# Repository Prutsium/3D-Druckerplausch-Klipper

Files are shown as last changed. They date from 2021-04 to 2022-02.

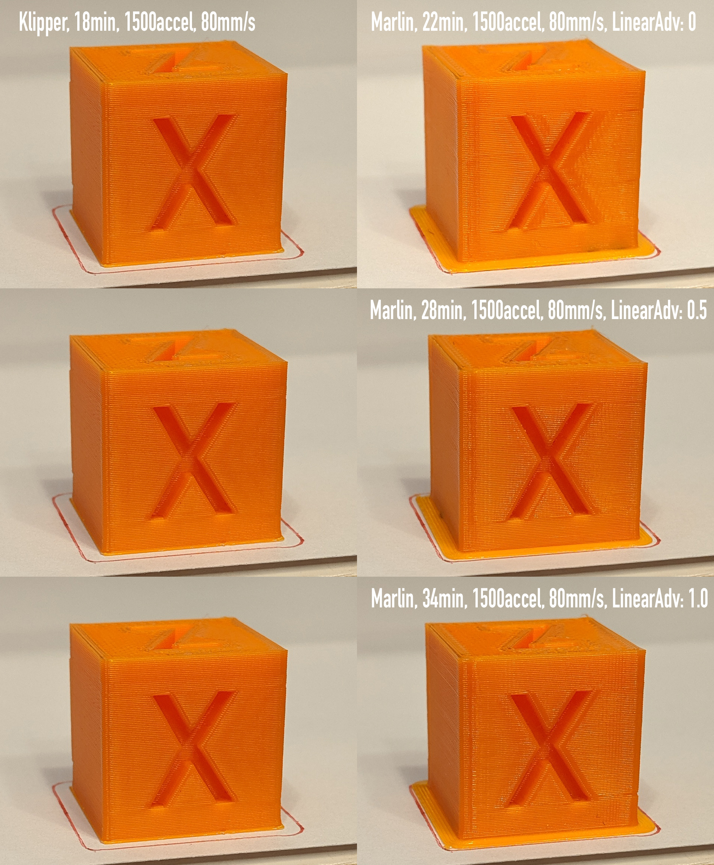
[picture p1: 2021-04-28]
images/KlipperVsMarlin.jpg

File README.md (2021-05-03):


Find us on Telegram: https://t.me/Druckerplausch

Repo for config file(s) for Prusa MK3(S)(+) and others with Klipper

Please see the wiki for advanced information how we set up Klipper on our Prusa printers.

This repository is meant in general for klipper but has a big focus on Prusa MK3(S)(+) with Klipper.
We try to collect here first of all working and complete configurations and these have been build up in a modular way so it would be easy to add or remove something or when we add a specific config for a specific part you wont need to modify your configuration but just include it in your original configuration.

We are still in a setup process but we try to document as much as possible.

The Wiki will be a main guideline on how to flash but also explanations how certain parts work.

# ToDo

- Klipper Setup on Raspberry and Prusa
- Restore Prusa firmware
- Config file description and how includes work
- 3-Axis tilt module -> resonance etc
- ...

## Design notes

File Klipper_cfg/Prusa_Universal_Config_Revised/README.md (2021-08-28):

This is my new approach of making configs since i had to take care of 5 different configs i went for a Universal Prusa / Bear config set.
The most of you are using the Prusa / Bear with the stock Einsy. Personally i dont use the Einsy anymore but i use a Duet 3 Mini 5+ and a Octopus board.
This made keeping the other configs up to date for me difficult and as said had to replicate my edits on 5 other configs.

For this reason i went for a more universal config where more things are splitted out and makes updates more easy.
The main file will be printer.cfg but you will need all files to copu to your klipper_config.

If you like to add something dont edit the files as when i make updates those will be overwritten.
Instead of that add them to the printer.cfg at the end as they will overrule what is in the configs.
You even dont need to remove the old part as the new part will overwrite those settings.

The selection is by default for a stock prusa with the stock extruder and a Einsy board.
If you want to use something else then remove the corrospondig # infront of that config.

Contribution is appriciated please use the issue tracker from Git and if interesting / helpfull we can add those requests.

This config is made of parts of my own but also scraped from various Klipper channels.
A special thanks to Khuaong for helping with the MMU part, Q66 for some great additions and Alexz who is always assisting if i want to create some stupid macro :)

Make sure you make a copy of your old klipper configuration before copying this to the klipper_config folder.
Due i have to use some defaults for PID and Z_Offset i suggest you copy from your old config the part that say's do not edit like the following example
#*# <---------------------- SAVE_CONFIG ---------------------->
#*# DO NOT EDIT THIS BLOCK OR BELOW. The contents are auto-generated.

Copy the whole block with contents and put this in the printer.cfg and run PID tuning after that for the bed and extruder.

Also add your MCU in mcu.cfg as then i can create update on the cfg's without overwriteing your MCU settings
I use a simplified way of MCU selection through Symlinks so you dont have to bother about the wier name like: usb-Klipper_stm32f446xx_3D002A000950534E4E313020-if00
But after creating a Symlink it would be: btt-octopus-11.

To create a Symlink use the following commands on your Pi:
pi@fluiddpi:~ $ lsusb
Bus 002 Device 001: ID 1d6b:0003 Linux Foundation 3.0 root hub
Bus 001 Device 037: ID 1d50:614e OpenMoko, Inc.
Bus 001 Device 002: ID 2109:3431 VIA Labs, Inc. Hub
Bus 001 Device 001: ID 1d6b:0002 Linux Foundation 2.0 root hub
pi@fluiddpi:~ $

In my case i am interested in the ID of the OpenMoko device what is the Octopus.
Next is to create the Symlink with the following command: (this will open the Nano editor with a blanc file)
sudo nano /etc/udev/rules.d/99-usb-serial.rules
Edit this file and put there: (in my example you see it for the Octopus)
SUBSYSTEMS=="usb", ATTRS{idProduct}=="614e",  ATTRS{idVendor}=="1d50", ACTION=="add", SYMLINK+="btt-octopus-11"

Save this file with CTRL-X and check if the printer has now a new name with ls /dev it should show there the name of the printer.
Now edit mcu.cfg (n ano ~/klipper_config/mcu.cfg ) and make the serial line like this (with your printer name)
serial: /dev/btt-octopus-11
Save it with CTRL-X and done you now can reach the printer by an easy name.

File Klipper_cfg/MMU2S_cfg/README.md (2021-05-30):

This is a new approach to use the MMU as the basis from Kakou was to restricted

User settings to do:
variable_bowden_load_length1: 505
variable_bowden_load_length2: 5
variable_bowden_unload_length: 520
variable_load_in_extruder: 52 # how much filament to load into extruder
variable_unload_in_extruder1: 32 
variable_unload_in_extruder2: 50

Dont forget to update your start Gcode in SuperSlicer and make sure it exports Klipper Gcode.
SET_GCODE_VARIABLE MACRO=START_PRINT_MMU VARIABLE=BED_TEMP VALUE=[first_layer_bed_temperature]
SET_GCODE_VARIABLE MACRO=START_PRINT_MMU VARIABLE=EXTRUDER_TEMP VALUE=[first_layer_temperature]
SET_GCODE_VARIABLE MACRO=START_PRINT_MMU VARIABLE=LOAD VALUE=[initial_tool]
START_PRINT_MMU

And as end print Gcode: END_PRINT_MMU

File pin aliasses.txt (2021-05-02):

# This file contains common board aliases for Arduino (and similar)
# boards.

# See docs/Config_Reference.md for a description of parameters.

# Arduino aliases for atmega168/328/328p boards
[board_pins arduino-standard]
aliases:
    ar0=PD0, ar1=PD1, ar2=PD2, ar3=PD3, ar4=PD4,
    ar5=PD5, ar6=PD6, ar7=PD7, ar8=PB0, ar9=PB1,
    ar10=PB2, ar11=PB3, ar12=PB4, ar13=PB5, ar14=PC0,
    ar15=PC1, ar16=PC2, ar17=PC3, ar18=PC4, ar19=PC5,
    analog0=PC0, analog1=PC1, analog2=PC2, analog3=PC3, analog4=PC4,
    analog5=PC5, analog6=PE0, analog7=PE1

# Arduino aliases for atmega2560/1280 (Arduino mega) boards
[board_pins arduino-mega]
aliases:
    ar0=PE0, ar1=PE1, ar2=PE4, ar3=PE5, ar4=PG5,
    ar5=PE3, ar6=PH3, ar7=PH4, ar8=PH5, ar9=PH6,
    ar10=PB4, ar11=PB5, ar12=PB6, ar13=PB7, ar14=PJ1,
    ar15=PJ0, ar16=PH1, ar17=PH0, ar18=PD3, ar19=PD2,
    ar20=PD1, ar21=PD0, ar22=PA0, ar23=PA1, ar24=PA2,
    ar25=PA3, ar26=PA4, ar27=PA5, ar28=PA6, ar29=PA7,
    ar30=PC7, ar31=PC6, ar32=PC5, ar33=PC4, ar34=PC3,
    ar35=PC2, ar36=PC1, ar37=PC0, ar38=PD7, ar39=PG2,
    ar40=PG1, ar41=PG0, ar42=PL7, ar43=PL6, ar44=PL5,
    ar45=PL4, ar46=PL3, ar47=PL2, ar48=PL1, ar49=PL0,
    ar50=PB3, ar51=PB2, ar52=PB1, ar53=PB0, ar54=PF0,
    ar55=PF1, ar56=PF2, ar57=PF3, ar58=PF4, ar59=PF5,
    ar60=PF6, ar61=PF7, ar62=PK0, ar63=PK1, ar64=PK2,
    ar65=PK3, ar66=PK4, ar67=PK5, ar68=PK6, ar69=PK7,
    analog0=PF0, analog1=PF1, analog2=PF2, analog3=PF3, analog4=PF4,
    analog5=PF5, analog6=PF6, analog7=PF7, analog8=PK0, analog9=PK1,
    analog10=PK2, analog11=PK3, analog12=PK4, analog13=PK5, analog14=PK6,
    analog15=PK7,
    # Marlin adds these additional aliases
    ml70=PG4, ml71=PG3, ml72=PJ2, ml73=PJ3, ml74=PJ7,
    ml75=PJ4, ml76=PJ5, ml77=PJ6, ml78=PE2, ml79=PE6,
    ml80=PE7, ml81=PD4, ml82=PD5, ml83=PD6, ml84=PH2,
    ml85=PH7

# Aliases for atmega644p (Sanguino boards)
[board_pins sanguino]
aliases:
    ar0=PB0, ar1=PB1, ar2=PB2, ar3=PB3, ar4=PB4,
    ar5=PB5, ar6=PB6, ar7=PB7, ar8=PD0, ar9=PD1,
    ar10=PD2, ar11=PD3, ar12=PD4, ar13=PD5, ar14=PD6,
    ar15=PD7, ar16=PC0, ar17=PC1, ar18=PC2, ar19=PC3,
    ar20=PC4, ar21=PC5, ar22=PC6, ar23=PC7, ar24=PA0,
    ar25=PA1, ar26=PA2, ar27=PA3, ar28=PA4, ar29=PA5,
    ar30=PA6, ar31=PA7,
    analog0=PA0, analog1=PA1, analog2=PA2, analog3=PA3, analog4=PA4,
    analog5=PA5, analog6=PA6, analog7=PA7

# Aliases for atsam3x8e (Arduino Due boards)
[board_pins arduino-due]
aliases:
    ar0=PA8, ar1=PA9, ar2=PB25, ar3=PC28, ar4=PA29,
    ar5=PC25, ar6=PC24, ar7=PC23, ar8=PC22, ar9=PC21,
    ar10=PA28, ar11=PD7, ar12=PD8, ar13=PB27, ar14=PD4,
    ar15=PD5, ar16=PA13, ar17=PA12, ar18=PA11, ar19=PA10,
    ar20=PB12, ar21=PB13, ar22=PB26, ar23=PA14, ar24=PA15,
    ar25=PD0, ar26=PD1, ar27=PD2, ar28=PD3, ar29=PD6,
    ar30=PD9, ar31=PA7, ar32=PD10, ar33=PC1, ar34=PC2,
    ar35=PC3, ar36=PC4, ar37=PC5, ar38=PC6, ar39=PC7,
    ar40=PC8, ar41=PC9, ar42=PA19, ar43=PA20, ar44=PC19,
    ar45=PC18, ar46=PC17, ar47=PC16, ar48=PC15, ar49=PC14,
    ar50=PC13, ar51=PC12, ar52=PB21, ar53=PB14, ar54=PA16,
    ar55=PA24, ar56=PA23, ar57=PA22, ar58=PA6, ar59=PA4,
    ar60=PA3, ar61=PA2, ar62=PB17, ar63=PB18, ar64=PB19,
    ar65=PB20, ar66=PB15, ar67=PB16, ar68=PA1, ar69=PA0,
    ar70=PA17, ar71=PA18, ar72=PC30, ar73=PA21, ar74=PA25,
    ar75=PA26, ar76=PA27, ar77=PA28, ar78=PB23,
    analog0=PA16, analog1=PA24, analog2=PA23, analog3=PA22, analog4=PA6,
    analog5=PA4, analog6=PA3, analog7=PA2, analog8=PB17, analog9=PB18,
    analog10=PB19, analog11=PB20

# Aliases for Adafruit GrandCentral boards (samd51)
[board_pins adafruit-grandcentral]
aliases:
    ar0=PB25, ar1=PB24, ar2=PC18, ar3=PC19, ar4=PC20,
    ar5=PC21, ar6=PD20, ar7=PD21, ar8=PB18, ar9=PB2,
    ar10=PB22, ar11=PB23, ar12=PB0, ar13=PB1, ar14=PB16,
    ar15=PB17, ar16=PC22, ar17=PC23, ar18=PB12, ar19=PB13,
    ar20=PB20, ar21=PB21, ar22=PD12, ar23=PA15, ar24=PC17,
    ar25=PC16, ar26=PA12, ar27=PA13, ar28=PA14, ar29=PB19,
    ar30=PA23, ar31=PA22, ar32=PA21, ar33=PA20, ar34=PA19,
    ar35=PA18, ar36=PA17, ar37=PA16, ar38=PB15, ar39=PB14,
    ar40=PC13, ar41=PC12, ar42=PC15, ar43=PC14, ar44=PC11,
    ar45=PC10, ar46=PC6, ar47=PC7, ar48=PC4, ar49=PC5,
    ar50=PD11, ar51=PD8, ar52=PD9, ar53=PD10, ar54=PA2,
    ar55=PA5, ar56=PB3, ar57=PC0, ar58=PC1, ar59=PC2,
    ar60=PC3, ar61=PB4, ar62=PB5, ar63=PB6, ar64=PB7,
    ar65=PB8, ar66=PB9, ar67=PA4, ar68=PA6, ar69=PA7,
    analog0=PA2, analog1=PA5, analog2=PB3, analog3=PC0, analog4=PC1,
    analog5=PC2, analog6=PC3, analog7=PB4, analog8=PB5, analog9=PB6,
    analog10=PB7, analog11=PB8, analog12=PB9, analog13=PA4, analog14=PA6,
    analog15=PA7

# Aliases for Beaglebone boards
[board_pins beaglebone]
aliases:
    P8_3=gpio1_6, P8_4=gpio1_7, P8_5=gpio1_2,
    P8_6=gpio1_3, P8_7=gpio2_2, P8_8=gpio2_3,
    P8_9=gpio2_5, P8_10=gpio2_4, P8_11=gpio1_13,
    P8_12=gpio1_12, P8_13=gpio0_23, P8_14=gpio0_26,
    P8_15=gpio1_15, P8_16=gpio1_14, P8_17=gpio0_27,
    P8_18=gpio2_1, P8_19=gpio0_22, P8_20=gpio1_31,
    P8_21=gpio1_30, P8_22=gpio1_5, P8_23=gpio1_4,
    P8_24=gpio1_1, P8_25=gpio1_0, P8_26=gpio1_29,
    P8_27=gpio2_22, P8_28=gpio2_24, P8_29=gpio2_23,
    P8_30=gpio2_25, P8_31=gpio0_10, P8_32=gpio0_11,
    P8_33=gpio0_9, P8_34=gpio2_17, P8_35=gpio0_8,
    P8_36=gpio2_16, P8_37=gpio2_14, P8_38=gpio2_15,
    P8_39=gpio2_12, P8_40=gpio2_13, P8_41=gpio2_10,
    P8_42=gpio2_11, P8_43=gpio2_8, P8_44=gpio2_9,
    P8_45=gpio2_6, P8_46=gpio2_7, P9_11=gpio0_30,
    P9_12=gpio1_28, P9_13=gpio0_31, P9_14=gpio1_18,
    P9_15=gpio1_16, P9_16=gpio1_19, P9_17=gpio0_5,
    P9_18=gpio0_4, P9_19=gpio0_13, P9_20=gpio0_12,
    P9_21=gpio0_3, P9_22=gpio0_2, P9_23=gpio1_17,
    P9_24=gpio0_15, P9_25=gpio3_21, P9_26=gpio0_14,
    P9_27=gpio3_19, P9_28=gpio3_17, P9_29=gpio3_15,
    P9_30=gpio3_16, P9_31=gpio3_14, P9_41=gpio0_20,
    P9_42=gpio3_20, P9_43=gpio0_7, P9_44=gpio3_18,
    P9_33=AIN4, P9_35=AIN6, P9_36=AIN5, P9_37=AIN2,
    P9_38=AIN3, P9_39=AIN0, P9_40=AIN1

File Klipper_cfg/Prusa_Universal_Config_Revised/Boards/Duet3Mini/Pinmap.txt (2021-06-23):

PinNames

nullptr			},	// PA00 TMC UART TxD
nullptr			},	// PA01 TMC UART RxD
"ate.lcd.a0"	},	// PA02 LCD A0
"ate.sbc.dr"	},	// PA03 SBC data ready
nullptr			},	// PA04 SBC SPI MISO
nullptr			},	// PA05 SBC SPI SCLK
nullptr			},	// PA06 SBC SPI SS
nullptr			},	// PA07 SBC SPI MOSI
nullptr			},	// PA08 Neopixel output (QSPI MOSI)
"are.lcd.buzz"	},	// PA09 LCD buzzer
"ate.d0.diag"	},	// PA10 driver 0 diag
"out4"			},	// PA11 OUT4
nullptr			},	// PA12 Ethernet/WiFi SCLK (SERCOM4.1)
nullptr			},	// PA13 Ethernet/WiFi MISO (SERCOM4.0)
nullptr			},	// PA14 Ethernet/WiFi SS (SERCOM4.2)
nullptr			},	// PA15 Ethernet/WiFi MOSI (SERCOM4.3)
nullptr			},	// PA16 Ethernet GCLK2 out/WiFi RxD (SERCOM3.1)
nullptr			},	// PA17 Ethernet/WiFi TxD (SERCOM3.0)
nullptr			},	// PA18 Ethernet/WiFi ESP_DATA_RDY
nullptr			},	// PA19 Ethernet/WiFi SAM_TRANSFER_RDY
nullptr			},	// PA20 SDHC CMD
nullptr			},	// PA21 SDHC CLK
"ate.d2.diag"	},	// PA22 driver 2 diag
"ate.d3.diag"	},	// PA23 driver 3 diag
nullptr			},	// PA24 USB
nullptr			},	// PA25 USB
nullptr			},	// PA26 not on chip
"ate.d6.dir"	},	// PA27 driver 6 dir
nullptr			},	// PA28 not on chip
nullptr			},	// PA29 not on chip
nullptr			},	// PA30 swclk/ACT LED
nullptr			},	// PA31 swdio/STATUS LED
"ate.d5.dir"	},	// PB00 driver 5 dir
"out6,laser,vfd" },	// PB01 OUT6
"out5"			},	// PB02 OUT5
"ate.d0.dir"	},	// PB03 driver 0 dir
nullptr			},	// PB04 VssaMon
nullptr			},	// PB05 VrefMon
"ate.vbus"		},	// PB06 Vbus
"io3.in"		},	// PB07 IO3_IN
"ate.d1.diag"	},	// PB08 driver 1 diag
"ate.enc.sw"	},	// PB09 ENC SW
"ate.d5.diag"	},	// PB10 driver 5 diag
"out3"			},	// PB11 OUT3
"io3.out"		},	// PB12 IO3_OUT
"out2"			},	// PB13 OUT2
nullptr			},	// PB14 CAN Tx
nullptr			},	// PB15 CAN Rx
"ate.cd"		},	// PB16 SD CD
"out0"			},	// PB17 OUT0
nullptr			},	// PB18 SD DAT0
nullptr			},	// PB19 SD DAT1
nullptr			},	// PB20 SD DAT2
nullptr			},	// PB21 SD DAT3
nullptr			},	// PB22 crystal XIN1
nullptr			},	// PB23 crystal XOUT1
"io0.in"		},	// PB24 IO0_IN
"io0.out"		},	// PB25 IO0_OUT
"out4.tach"		},	// PB26 OUT4 tacho
"out3.tach"		},	// PB27 OUT3 tacho
"ate.d2.dir"	},	// PB28 driver 2 dir
"ate.d1.dir"	},	// PB29 driver 1 dir
"io1.in"		},	// PB30 IO1_IN
"io1.out"		},	// PB31 IO1_OUT
"temp0"			},	// PC00 thermistor0
"temp1"			},	// PC01 thermistor1
"temp2"			},	// PC02 thermistor2
"ate.vin"		},	// PC03 VIN monitor
"io5.in"		},	// PC04 IO5_IN
"io4.in"		},	// PC05 IO4_IN
"spi.cs3"		},	// PC06 SPI_CS3
"spi.cs2"		},	// PC07 SPI CS2
nullptr			},	// PC08 not on chip
nullptr			},	// PC09 not on chip
"out1"			},	// PC10 OUT1
"ate.enc.a"		},	// PC11 ENC A
nullptr			},	// PC12 SPI MOSI
nullptr			},	// PC13 SPI SCK
nullptr			},	// PC14 SPI CS0 (external SD card)
nullptr			},	// PC15 SPI_MISO
"ate.d4.step"	},	// PC16 driver4 step
nullptr			},	// PC17 phy reset/ESP reset
"ate.d6.step"	},	// PC18 driver 6 step
"ate.d3.step"	},	// PC19 driver 3 step
nullptr			},	// PC20 Ethernet/WiFi ESP_EN
"ate.d6.diag"	},	// PC21 driver 4 diag
nullptr			},	// PC22 Ethernet
nullptr			},	// PC23 Ethernet
"ate.d2.step"	},	// PC24 driver2 step
"ate.d1.step"	},	// PC25 driver1 step
"ate.d0.step"	},	// PC26 driver0 step
"ate.d6.diag"	},	// PC27 driver 6 diag
nullptr			},	// PC28 driver ENN
nullptr			},	// PC29 not on chip
"ate.d5.step"	},	// PC30 driver 5 step
"io6.in"		},	// PC31 IO6_IN
nullptr			},	// PD00 drivers UART mux
"ate.enc.b"		},	// PD01 ENC B
nullptr			},	// PD02 not on chip
nullptr			},	// PD03 not on chip
nullptr			},	// PD04 not on chip
nullptr			},	// PD05 not on chip
nullptr			},	// PD06 not on chip
nullptr			},	// PD07 not on chip
"io2.in"		},	// PD08 IO2_IN
"io2.out"		},	// PD09 IO2_OUT
"io4.out,pson"	},	// PD10 IO4_OUT and PS_ON
"spi.cs1"		},	// PD11 SPI2 CS1
"ate.spi2.cd"	},	// PD12 SPI2_CD
nullptr		},	// PD13 not on chip
nullptr		},	// PD14 not on chip
nullptr		},	// PD15 not on chip
nullptr		},	// PD16 not on chip
nullptr		},	// PD17 not on chip
nullptr		},	// PD18 not on chip
nullptr		},	// PD19 not on chip
nullptr		},	// PD20 driver6 dir
nullptr		},	// PD21 driver5 dir
nullptr			},	// PA00 driver diag interrupt
nullptr			},	// PA01 drivers ENN
nullptr			},	// PA02 external SD card CD
nullptr			},	// PA03 drivers diag mux out
nullptr			},	// PA04 SBC SPI MISO
nullptr			},	// PA05 SBC SPI SCLK
nullptr			},	// PA06 SBC SPI SS
nullptr			},	// PA07 SBC SPI MOSI
nullptr			},	// PA08 Neopixel output (QSPI MOSI)
"out3"			},	// PA09 OUT3
"io3.in"		},	// PA10 IO3_IN
"out4"			},	// PA11
nullptr			},	// PA12 Ethernet/WiFi SCLK (SERCOM4.1)
nullptr			},	// PA13 Ethernet/WiFi MISO (SERCOM4.0)
nullptr			},	// PA14 Ethernet/WiFi SS (SERCOM4.2)
nullptr			},	// PA15 Ethernet/WiFi MOSI (SERCOM4.3)
nullptr			},	// PA16 Ethernet GCLK2 out/WiFi RxD (SERCOM3.1)
nullptr			},	// PA17 Ethernet/WiFi TxD (SERCOM3.0)
nullptr			},	// PA18 Ethernet/WiFi ESP_DATA_RDY
nullptr			},	// PA19 Ethernet/WiFi SAM_TRANSFER_RDY
nullptr			},	// PA20 SDHC CMD
nullptr			},	// PA21 SDHC CLK
nullptr			},	// PA22 12864 buzzer
nullptr			},	// PA23 driver diag mux S0
nullptr			},	// PA24 USB
nullptr			},	// PA25 USB
nullptr			},	// PA26 not on chip
nullptr			},	// PA27 driver0 dir
nullptr			},	// PA28 not on chip
nullptr			},	// PA29 not on chip
nullptr			},	// PA30 swclk/Ethernet LED Y
nullptr			},	// PA31 swdio/diag LED
nullptr			},	// PB00 driver4 dir
"out6,laser,vfd" },	// PB01 OUT6
"out5"			},	// PB02 OUT5
nullptr			},	// PB03 driver3 dir
nullptr			},	// PB04 VssaMon
nullptr			},	// PB05 VrefMon
nullptr			},	// PB06 Vbus
nullptr			},	// PB07 SBC data rdy
nullptr			},	// PB08 VinMon
nullptr			},	// PB09 ENC SW
nullptr			},	// PB10 driver diag mux S2
"out1"			},	// PB11 OUT1
"io3.out"		},	// PB12 IO3_OUT
"out2"			},	// PB13 OUT2
"io4.out"		},	// PB14 IO4_OUT
"io4.in"		},	// PB15 IO4_IN
nullptr			},	// PB16 SD CD
"out0"			},	// PB17 OUT0
nullptr			},	// PB18 SD DAT0
nullptr			},	// PB19 SD DAT1
nullptr			},	// PB20 SD DAT2
nullptr			},	// PB21 SD DAT3
nullptr			},	// PB22 crystal XIN1
nullptr			},	// PB23 crystal XOUT1
"io0.in"		},	// PB24 IO0_IN
"io0.out"		},	// PB25 IO0_OUT
"out4.tach"		},	// PB26 OUT4 tacho
"out3.tach"		},	// PB27 OUR3 tacho
nullptr			},	// PB28 driver 2 dir
nullptr			},	// PB29 driver 1 dir
"io1.in"		},	// PB30 IO1_IN
"io1.out"		},	// PB31 IO1_OUT
"temp0"			},	// PC00 thermistor0
"temp1"			},	// PC01 thermistor1
"temp2"			},	// PC02 thermistor2
nullptr			},	// PC03 12864 A0
"io6.in"		},	// PC04 IO6_IN
"io5.in"		},	// PC05 IO5_IN
"spi.cs3"		},	// PC06 SPI_CS3
"spi.cs2"		},	// PC07 SPI CS2
nullptr			},	// PC08 not on chip
nullptr			},	// PC09 not on chip
"spi.cs1"		},	// PC10 SPI CS1
nullptr			},	// PC11 ENC A
nullptr			},	// PC12 SPI MOSI
nullptr			},	// PC13 SPI SCK
nullptr			},	// PC14 SPI CS0 (external SD card)
nullptr			},	// PC15 SPI_MISO
nullptr			},	// PC16 driver4 step
nullptr			},	// PC17 driver7 dir
nullptr			},	// PC18 driver6 step
nullptr			},	// PC19 driver7 step
nullptr			},	// PC20 Ethernet/WiFi ESP_RST
nullptr			},	// PC21 Ethernet PHY_RST/WiFi ESP_EN
nullptr			},	// PC22 Ethernet
nullptr			},	// PC23 Ethernet
nullptr			},	// PC24 driver2 step
nullptr			},	// PC25 driver1 step
nullptr			},	// PC26 driver0 step
nullptr			},	// PC27 stepper TxD (SERCOM 1.0)
nullptr			},	// PC28 stepper RxD (SERCOM 1.1)
nullptr			},	// PC29 not on chip
nullptr			},	// PC30 driver5 step
nullptr			},	// PC31 driver3 step
nullptr			},	// PD00 drivers UART mux
nullptr			},	// PD01 ENC B
nullptr			},	// PD02 not on chip
nullptr			},	// PD03 not on chip
nullptr			},	// PD04 not on chip
nullptr			},	// PD05 not on chip
nullptr			},	// PD06 not on chip
nullptr			},	// PD07 not on chip
"io2.in"		},	// PD08 IO2_IN
"io2.out"		},	// PD09 IO2_OUT
"io5.out,pson"	},	// PD10 IO5_OUT and PS_ON
nullptr			},	// PD11 drivers diag mux S1
"io7.in"		},	// PD12

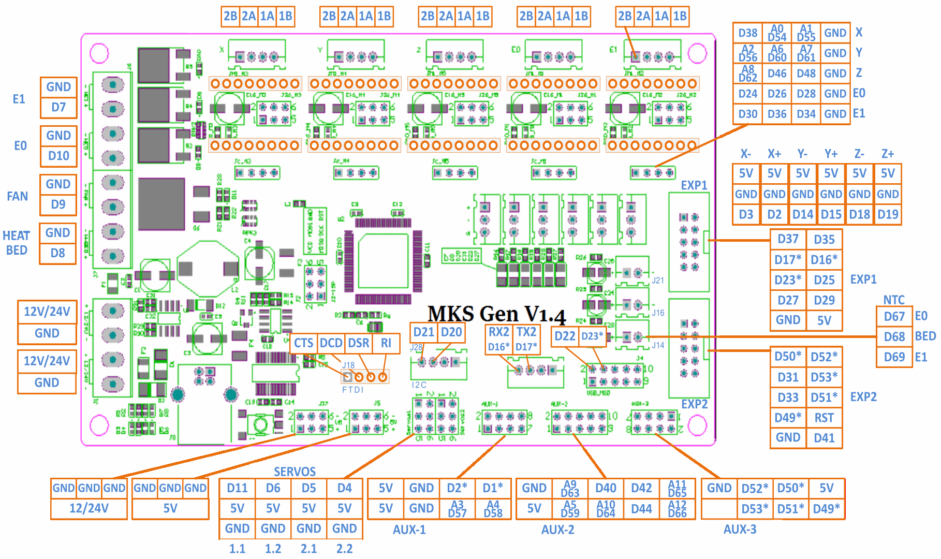
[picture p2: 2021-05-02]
Klipper_cfg/Frankenstein_MKS1.4_MK3_cfg/MksGenV14-Pinout.png

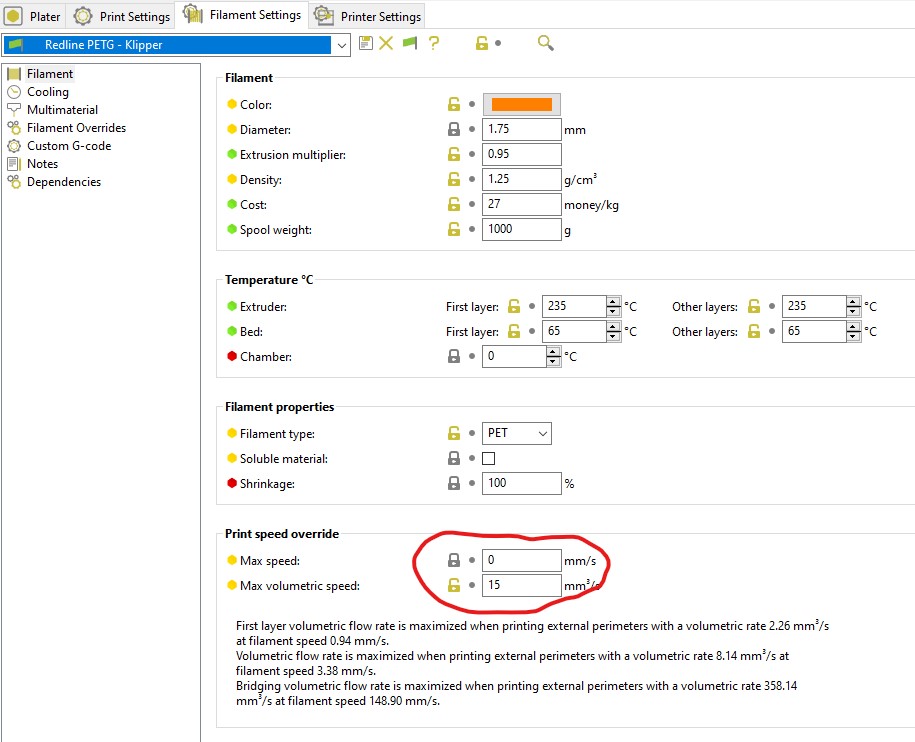
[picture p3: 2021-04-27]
images/slicer/SlicerFilament.jpg

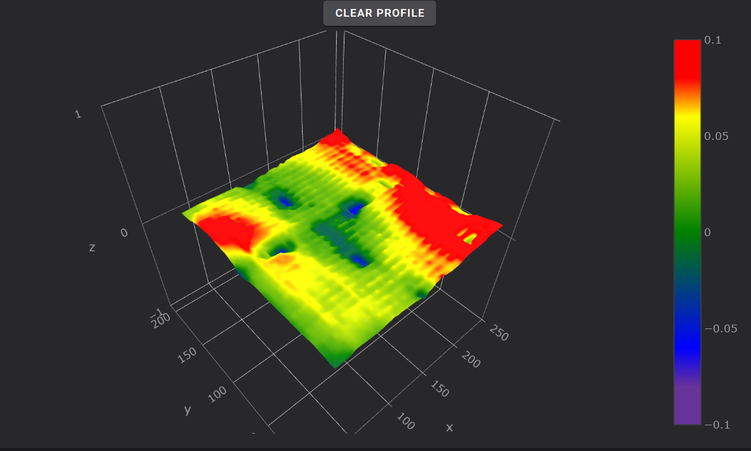
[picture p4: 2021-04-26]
images/SuperPinda1a.jpg

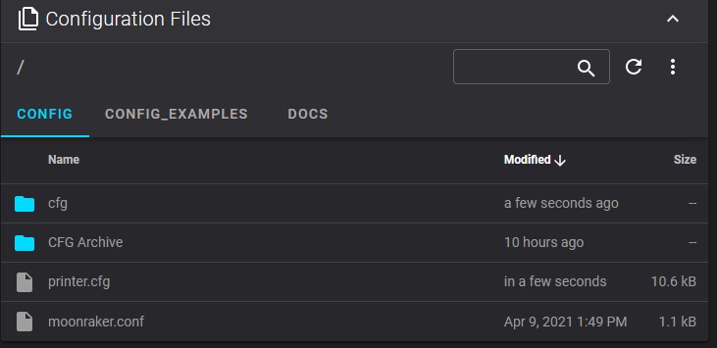
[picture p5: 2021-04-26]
images/Configfilesmenu.jpg

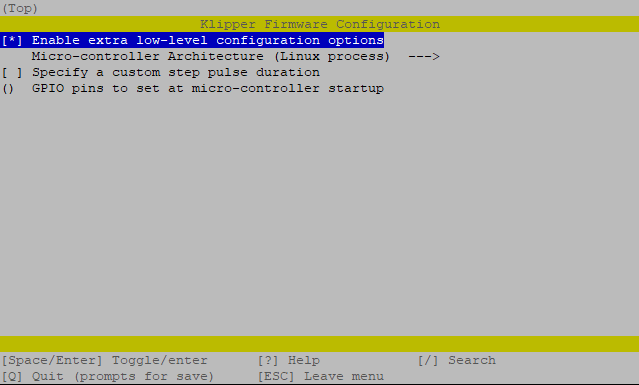
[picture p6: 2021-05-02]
doc/menuconfig_secondary_mcu.png

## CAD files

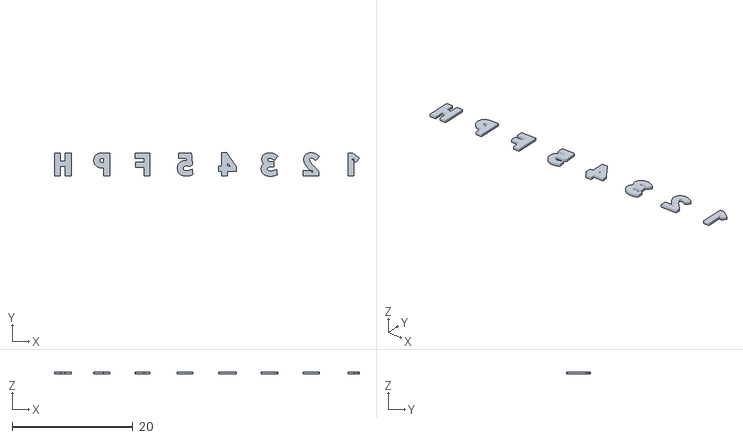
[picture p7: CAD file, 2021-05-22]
Klipper_cfg/Prusa_Universal_Config_Revised/MMU/Boards/SKR_Mini_v3/MMU Status LED - Letters Black.STL
50.5 x 3.94 x 0.4

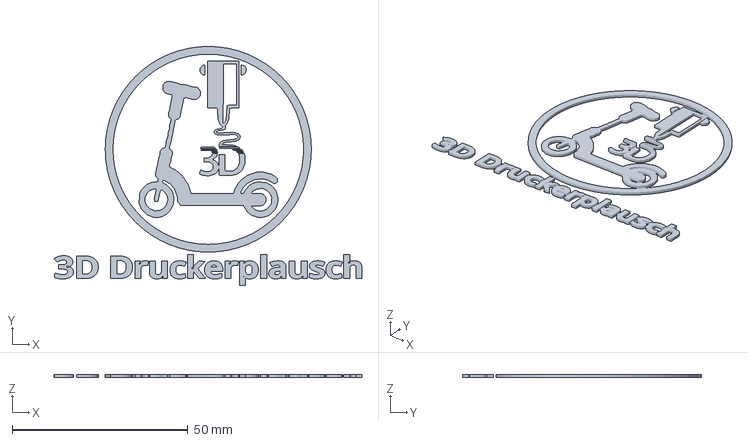
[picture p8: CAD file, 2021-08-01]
Klipper_cfg/WIP-Prusa_Universal config/SuperSlicer_config/Klipper settings JG.3mf
87.7 x 68.1 x 0.854 mm

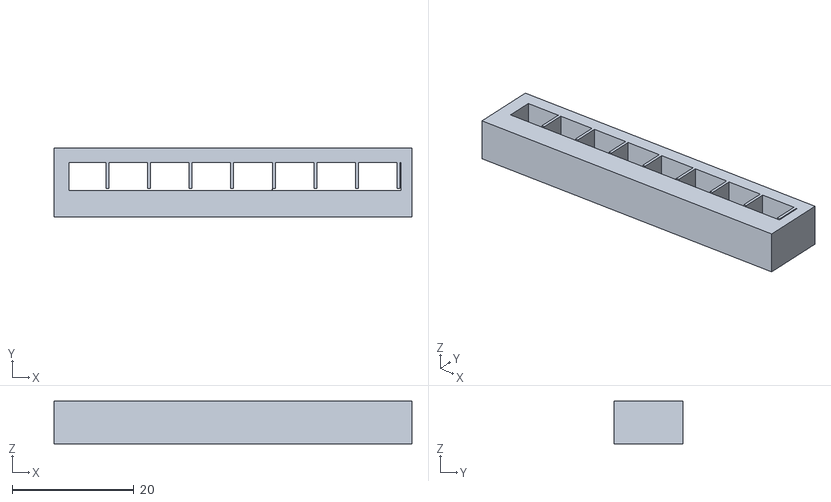
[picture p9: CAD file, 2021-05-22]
Klipper_cfg/Prusa_Universal_Config_Revised/MMU/Boards/SKR_Mini_v3/MMU Status LED - Case Black.stl
58.8 x 11.3 x 7.00

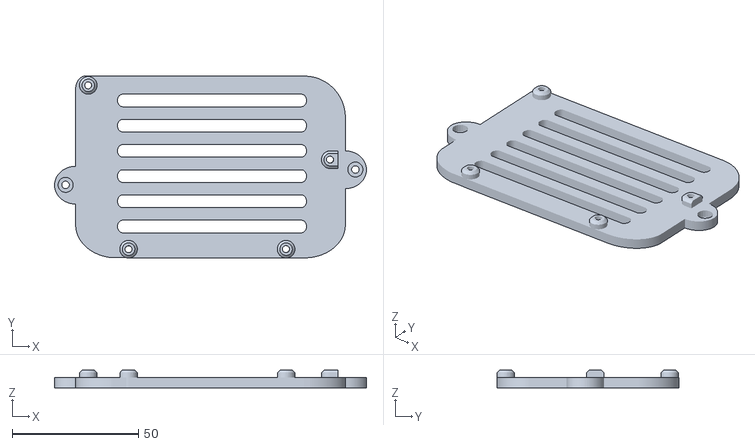
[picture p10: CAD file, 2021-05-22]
Klipper_cfg/Prusa_Universal_Config_Revised/MMU/Boards/SKR_Mini_v3/SKR Mini on MMU.stl
123.8 x 72.2 x 7.00

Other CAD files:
Klipper_cfg/Prusa_Universal_Config_Revised/MMU/Boards/SKR_Mini_v3/MMU Status LED - Background letters White.stl

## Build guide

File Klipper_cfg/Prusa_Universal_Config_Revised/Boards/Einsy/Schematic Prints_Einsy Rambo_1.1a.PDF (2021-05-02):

D | D
C | C
B | B
A | A

Cannot open
file
C:\Users\Aaron\
Documents\Libs
\Sch Template
UMLogo\logo_
Project: Einsy Rambo | Ver: 1.1 a
Title: * | File: Title.SchDoc
Drawn by: UltiMachine | Sheet: 1 of 11

# Einsy Rambo 1.1a

9/18/2017

# UltiMachine

0.3a Revision Summary (for detailed infomation goto: https://github.com/ultimachine/Einsy-Rambo/tree/0.3a
- Added TVS and over-voltage protection to select nets
- Added and corrected testpoints
- Added "XTRA0" net between 32U2 and 2560
- Removed via tenting underneath QFNs and other flat solder lug/heatsink primitives
- Added teardrops to vias
- Standardized via sizes to 10/22 and 15/30 (mils)
- New footprint for 5V SMPS inductor (fits two inductors now)
- Added I2C pullup footprints (resistors are "DNI")
- Fan connectors now have a 3rd pin for reading the TACH signal

Notes:
DNI Do Not Include
- Added 100R to the gate of each FET
- Adjusted the stackup to better reflect a standard 4-layer stack
= | = No Populate
- Updated paste mask apertures on QFNs
- Increased copper pour coverage
- Increased GND stitching
- Moved thermistor TPs to connector pin
- New footprint for P3
- Touchup diode polarity markings in silkscreen
- Removed RN4
- Added R73
- Added nAC_FAULT to pin_6 of Atmega2560
- Combined 2560 ICSP (X18) with pins_9-14 of J19
- Stole RX1 and TX1 from P1, moved to J19
- Added J7, power failure relay input.
- Removed J16-J18, X_MAX, Y_MAX, Z_MAX

0.4a Revision Summary

- Changed X_MIN and Y_MIN endstops to 2-pin headers
- Changed Z_MIN endstop to Z_PROBE, 4-pin header
- Combined DIAG_0 and DIAG_1 on TMC2130 drivers
- TP40 moved 0.1" to the left
- TP32 moved 0.1" to the left

0.5a Revision Summary
- Added ferrites to motor controller outputs.
- Removed fuse and input filter for VMOT
- Move MOSFET pulldown resistors to input side of AND gates
- Added ferrites to all P1 and P2 signals.
- Changed RN1 and RN2 from 10k to 5.6k (increases voltage on motor controller Vref pins)
- Changed motor controller low-side I-sense resistors from 0.1 to 0.22Ohm
- Voltage regulator U3 is now sourced from VMOT (was +12V2)
- Added power bypass capacitors to J7 and J15
- +12V2(Logic) and +12V3(Bed) now have micro-controller ADC based voltage monitoring.
- Added filtered internal island for micro-controller Vcc
- Added 2 internal layers (now 6 layers total)
- Most bottom layer routing (Layer 6) was moved to the new adjacent internal layer (Layer 5)
- Moved MOSFET pulldowns R43 and R57 upstream from FETs and placed at input of AND gate.
- New pinout for J19 header.
- Motor connectors are now flush with the bottom edge of the board.

1.0a Revision Summary
- Populate FGND to GND resistor ties

1.1a Revision Summary
- Added 2Mb serial flash
- Added voltage translators for serial flash
- Added tri-state buffer to block 3.3V MISO on the SD Card from the 5V MISO bus
- Added barrel-relief to bottom side of thermal vias for TMC2130, FETs and SMPS
- Added 3.3V LDO for serial flash

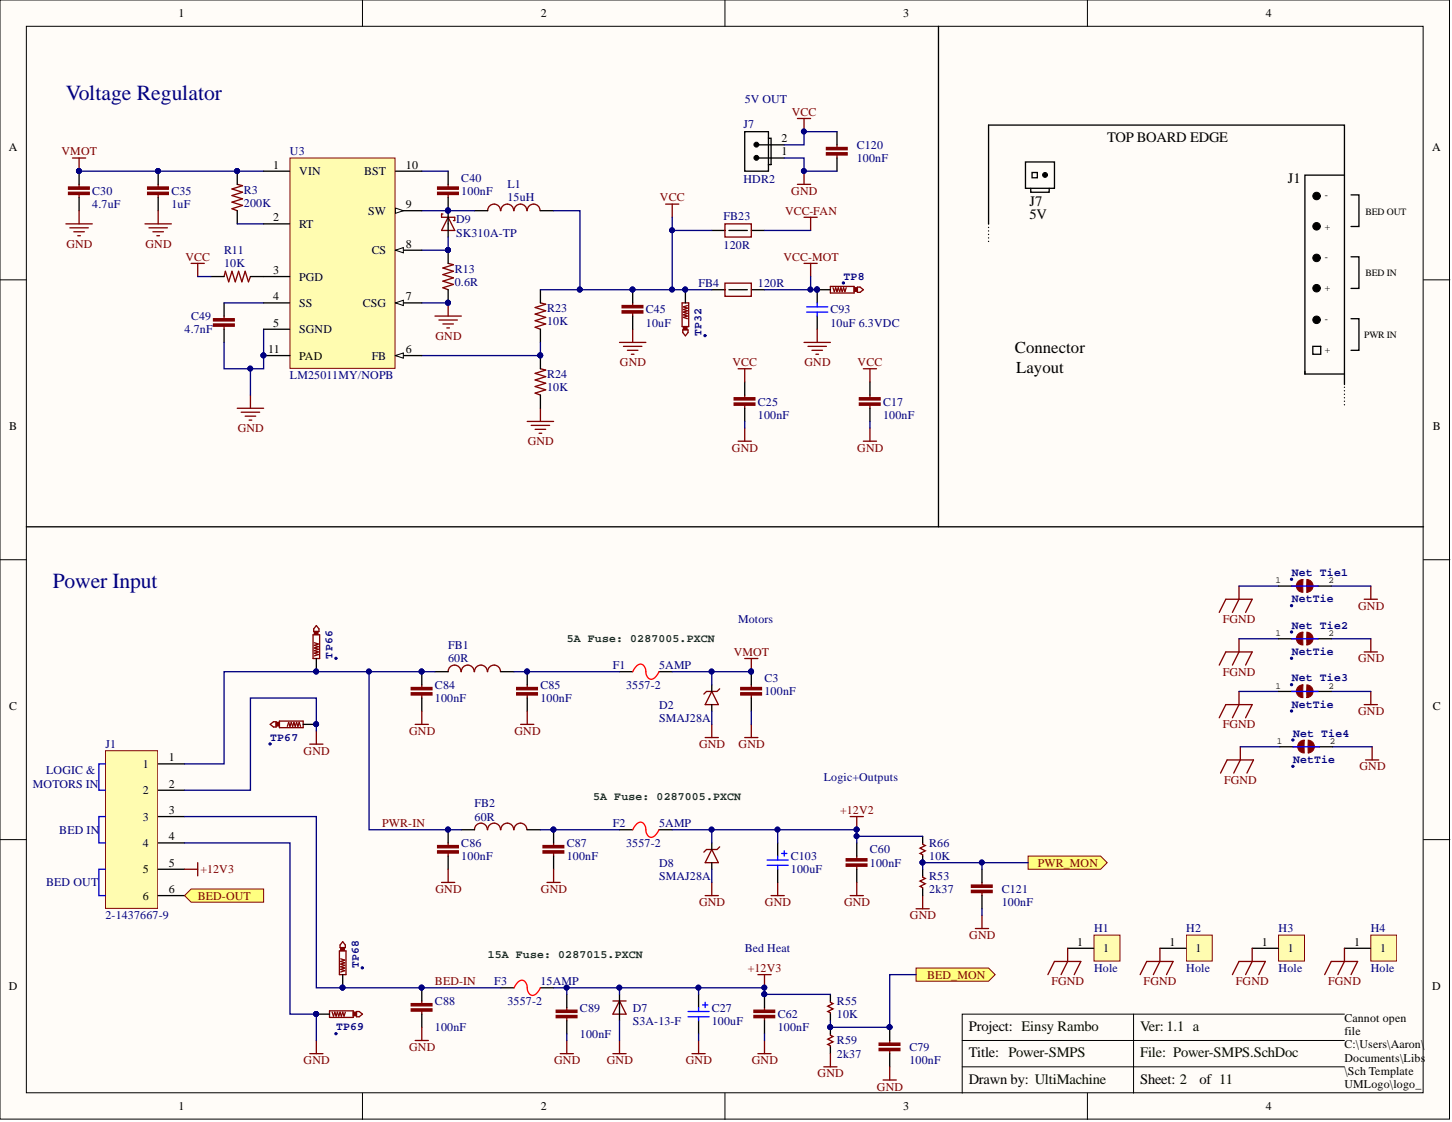
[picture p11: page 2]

Project: Einsy Rambo | Ver: 1.1 a

Power-SMPS | Power-SMPS.SchDoc

UltiMachine | 2 11

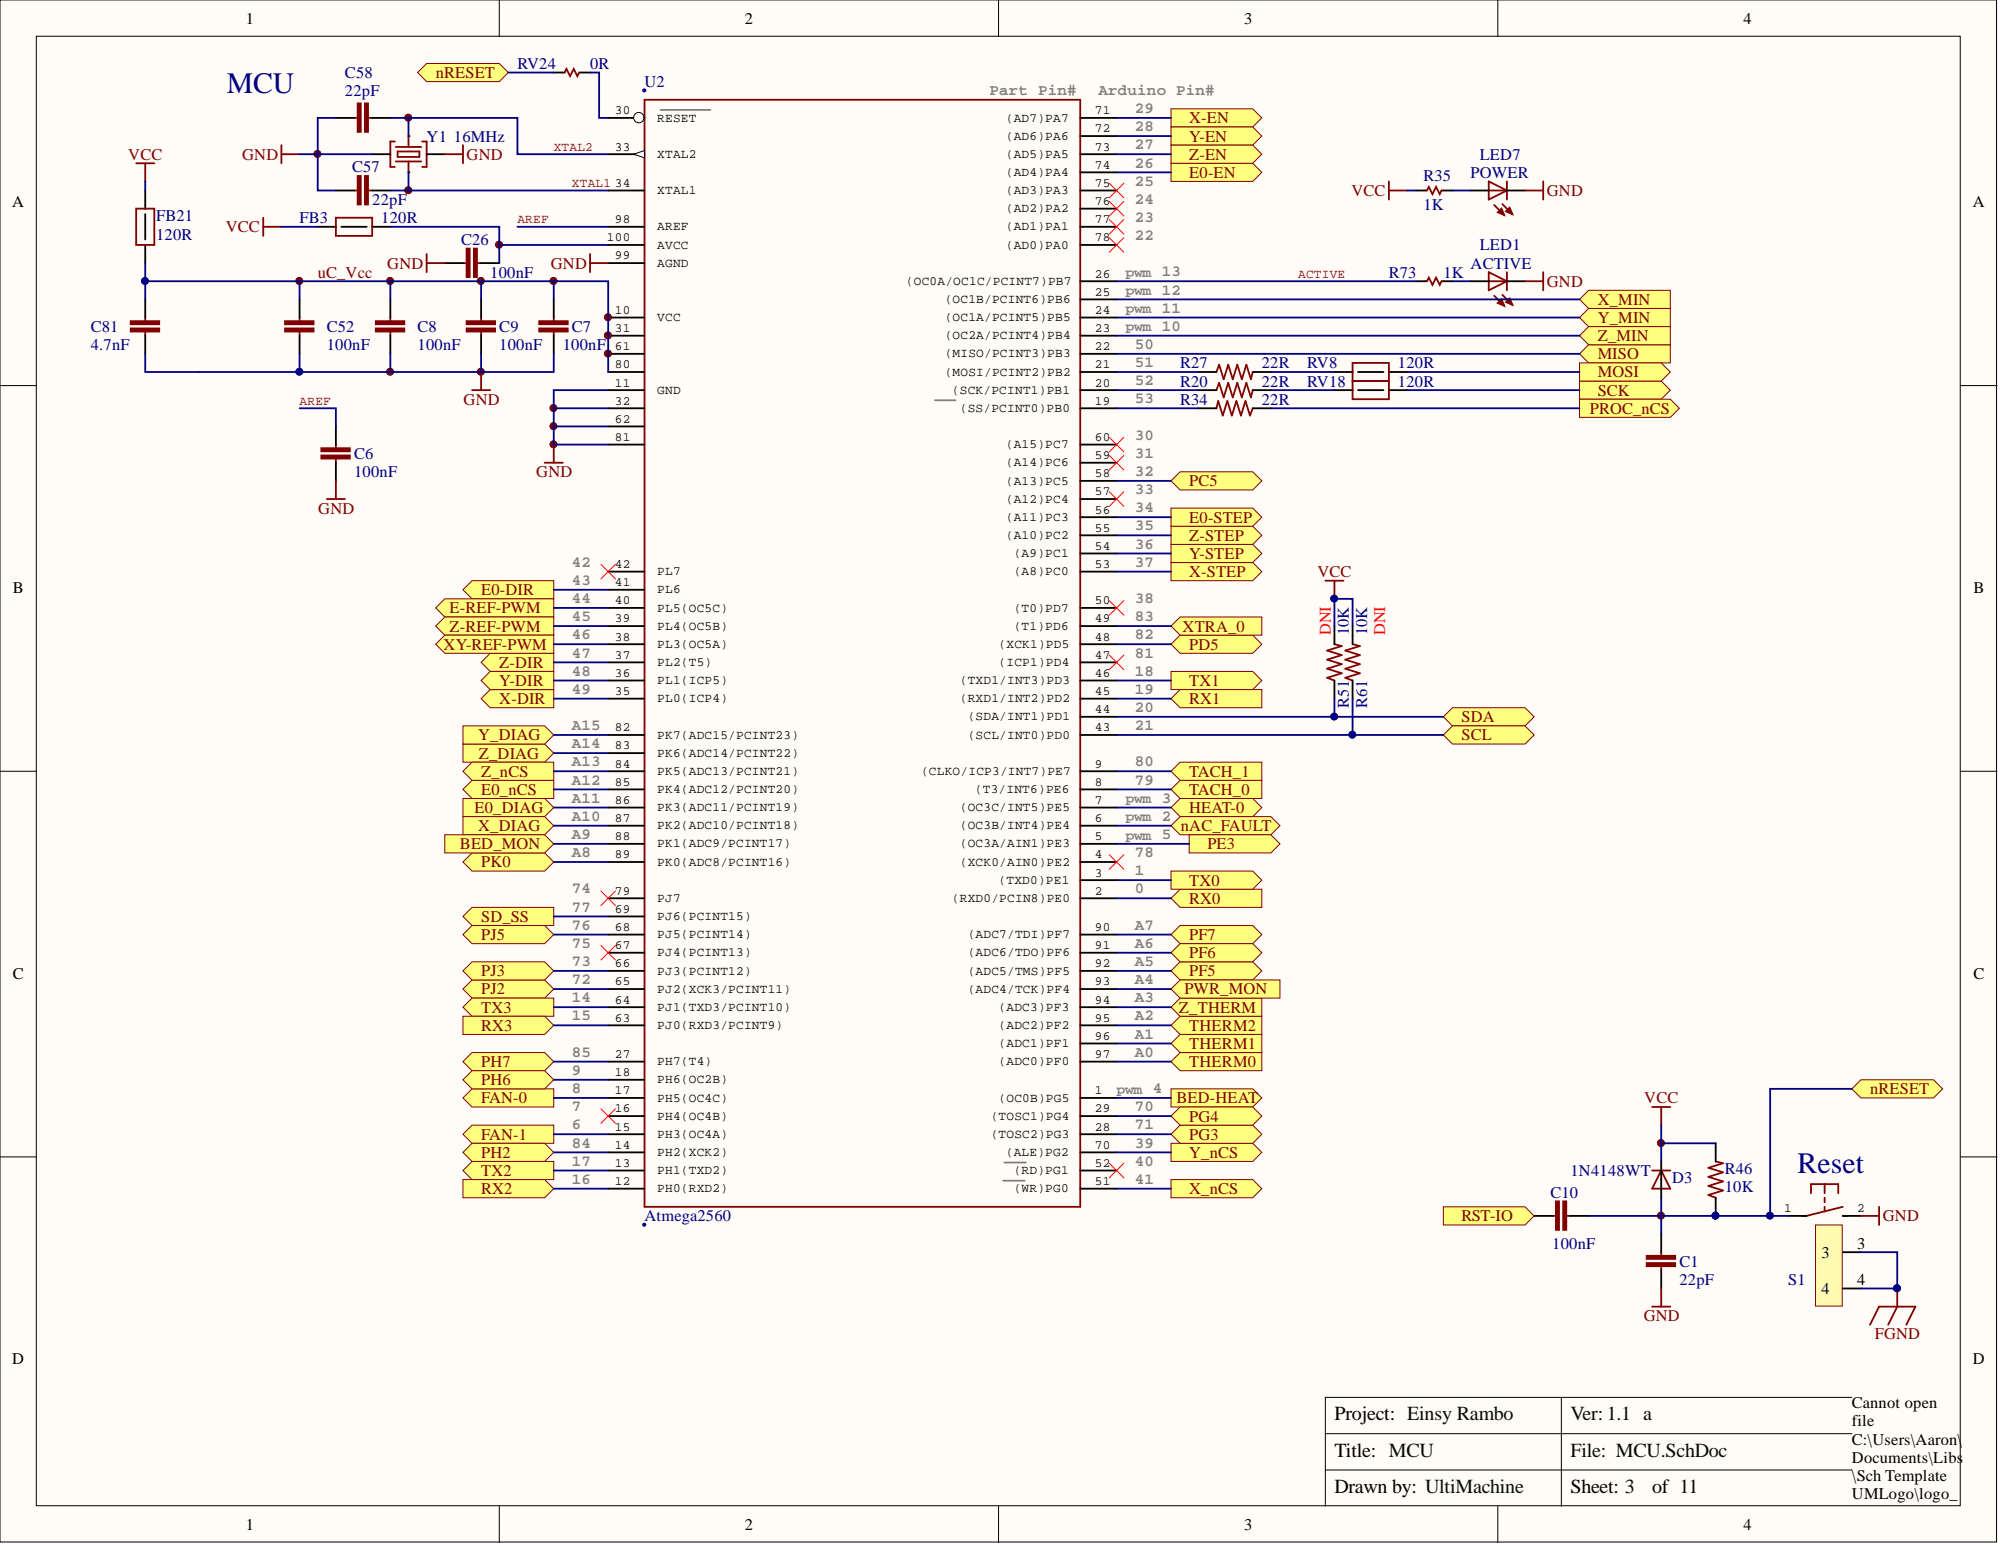
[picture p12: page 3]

32
62
81

Project: Einsy Rambo | Ver: 1.1 a

MCU | MCU.SchDoc

UltiMachine | 3 11

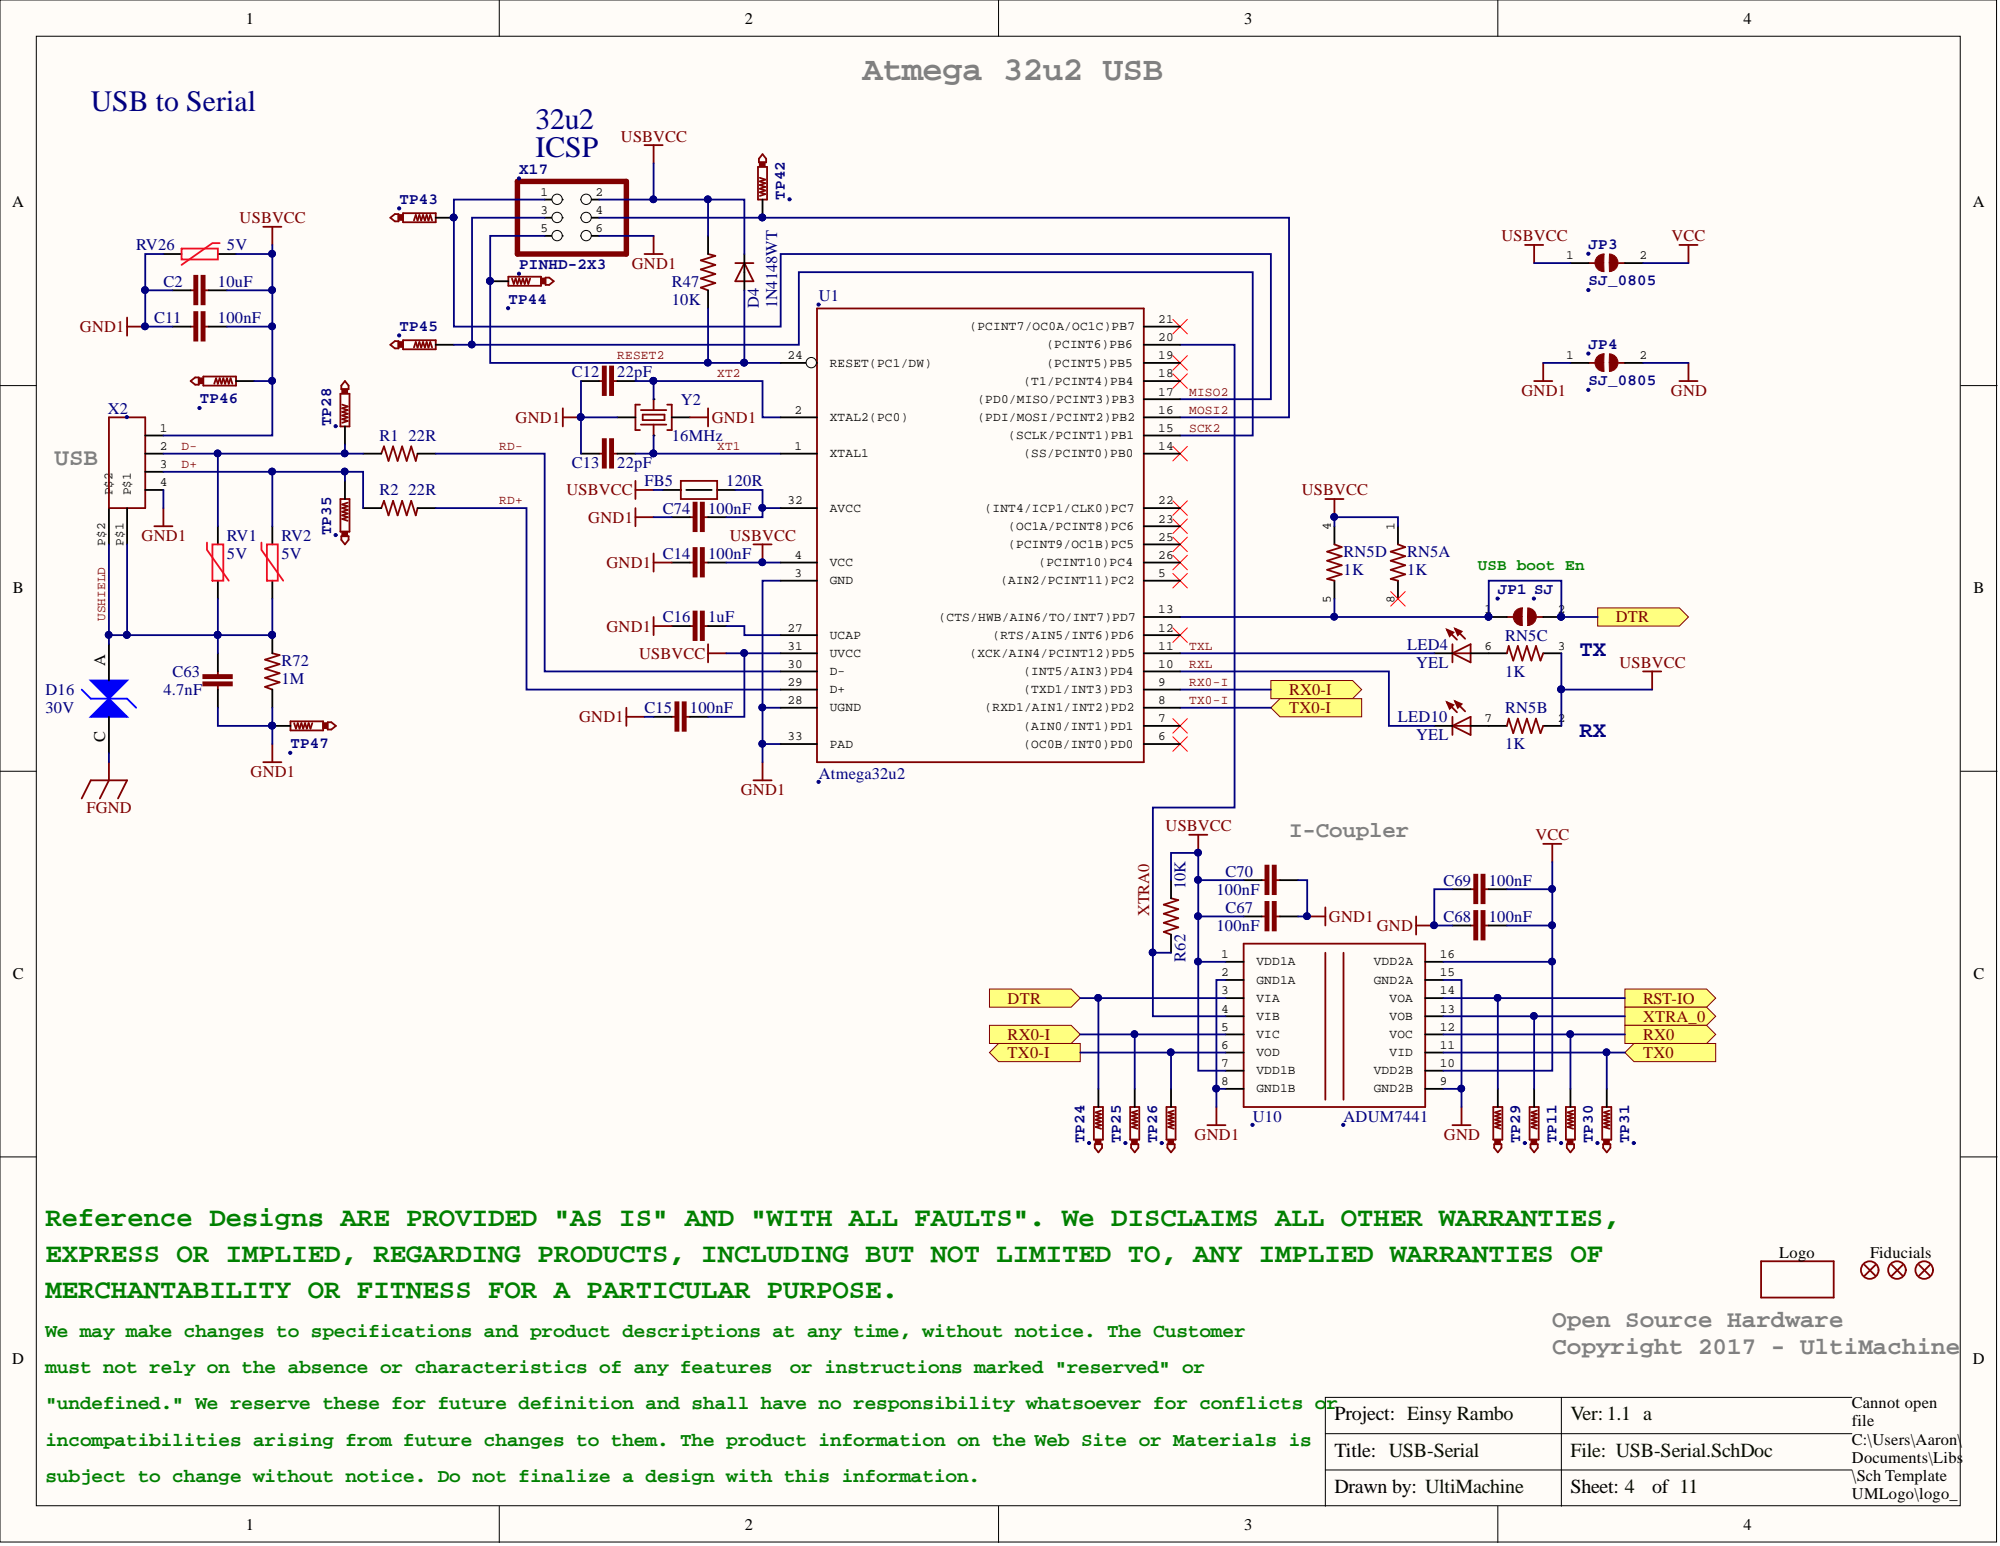
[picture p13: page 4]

3 4
5 | 6 | R47

VDD1A 1
GND1A 2

Reference Designs ARE PROVIDED "AS IS" AND "WITH ALL FAULTS". We DISCLAIMS ALL OTHER WARRANTIES,
EXPRESS OR IMPLIED, REGARDING PRODUCTS, INCLUDING BUT NOT LIMITED TO, ANY IMPLIED WARRANTIES OF
MERCHANTABILITY OR FITNESS FOR A PARTICULAR PURPOSE.

We may make changes to specifications and product descriptions at any time, without notice. The Customer
must not rely on the absence or characteristics of any features

or instructions marked "reserved" or

"undefined." We reserve these for future definition and shall have no responsibility whatsoever for conflicts or

Project: Einsy Rambo | Ver: 1.1 a

incompatibilities arising from future changes to them. The product information on the

Web Site or Materials is

USB-Serial | USB-Serial.SchDoc

subject to change without notice. Do not finalize a design with this information.

UltiMachine | 4 11

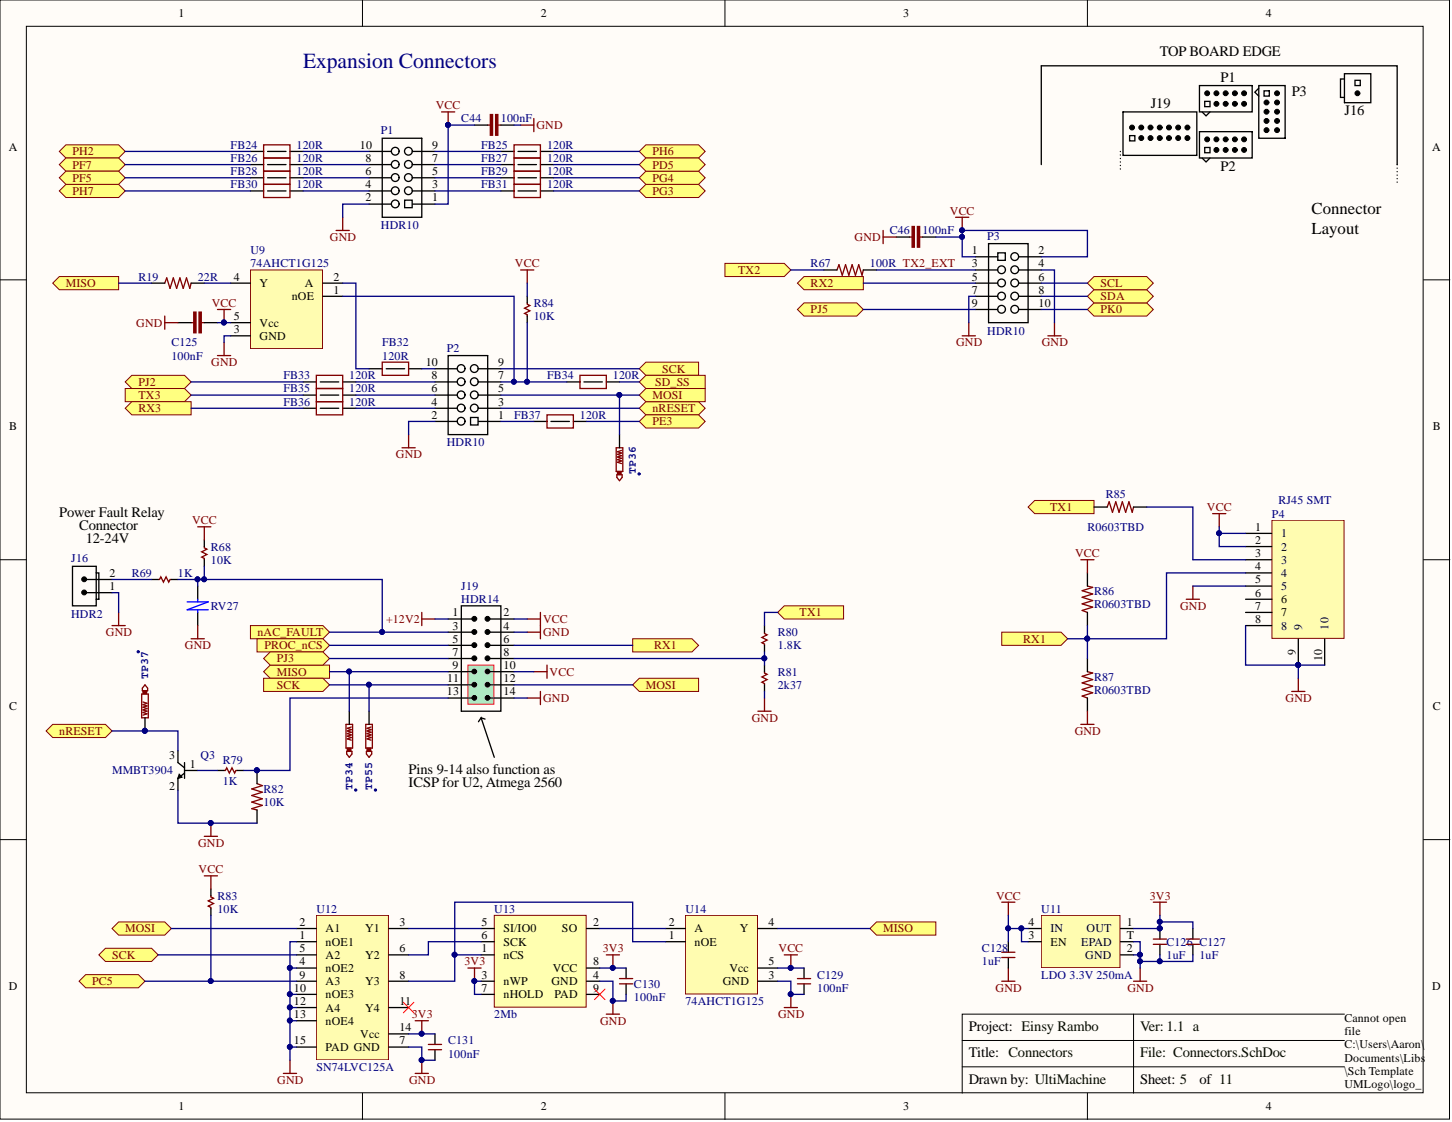
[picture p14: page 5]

Pins 9-14 also function as
ICSP for U2, Atmega 2560

nCS 1

nOE3 10 nOE4 13 PAD 15 | | nHOLD 7

Project: Einsy Rambo | Ver: 1.1 a

Connectors | Connectors.SchDoc

UltiMachine | 5 11

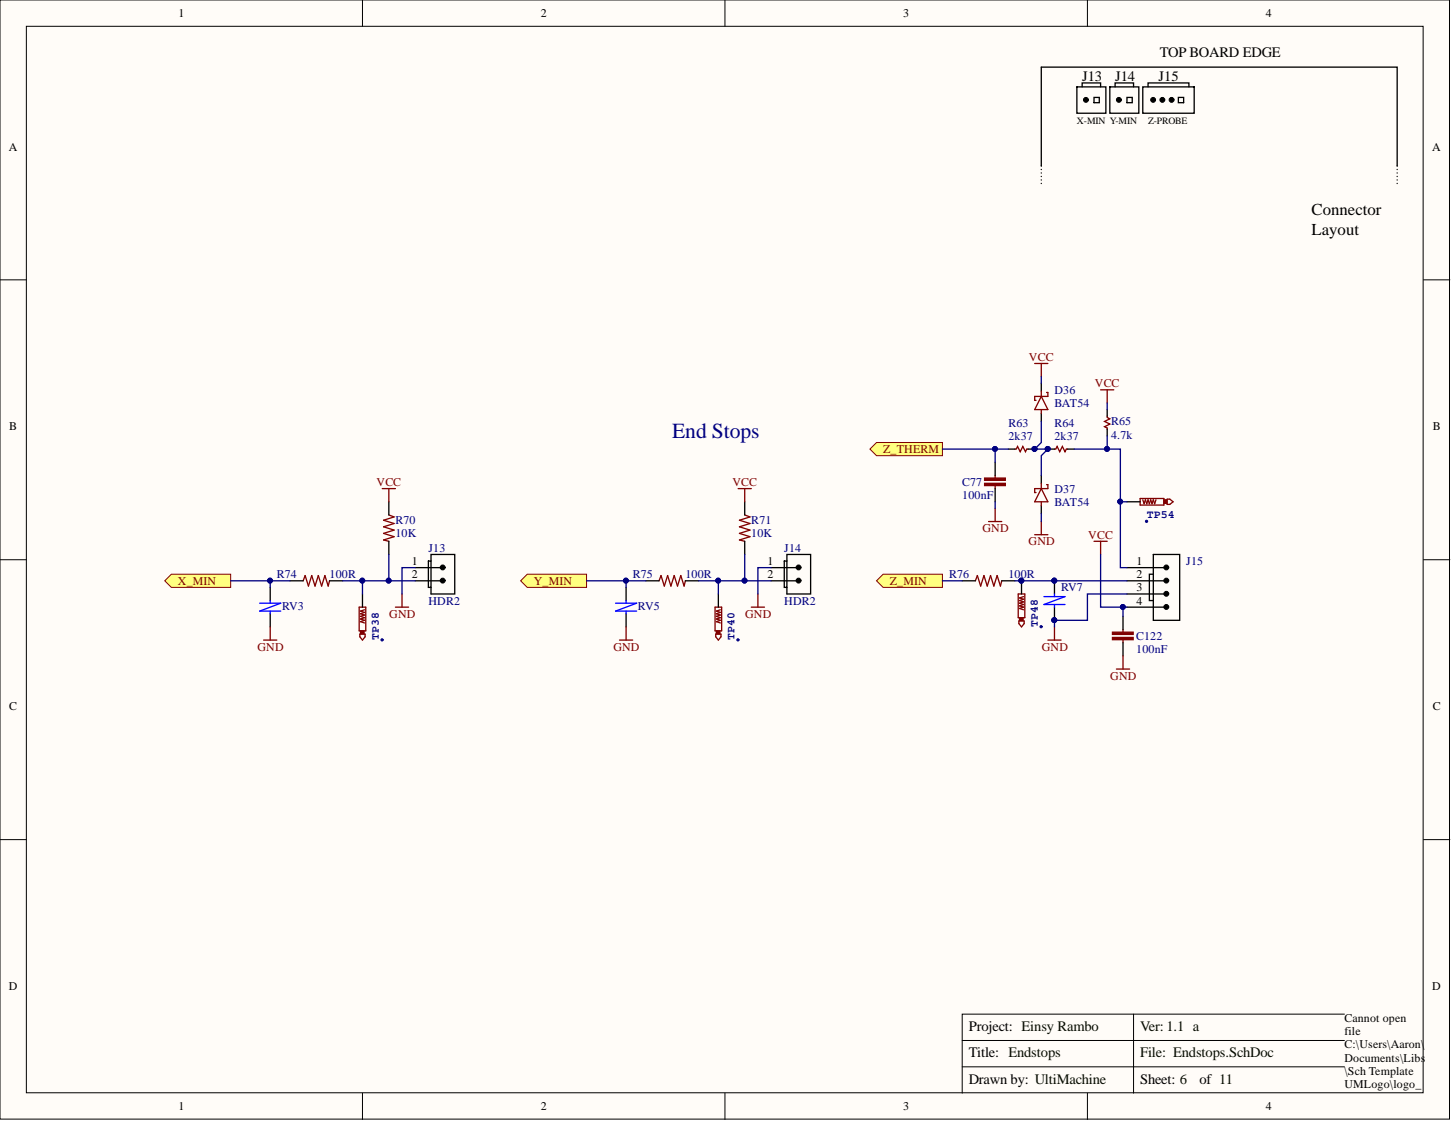
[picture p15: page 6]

Project: Einsy Rambo | Ver: 1.1 a

Endstops | Endstops.SchDoc

UltiMachine | 6 11

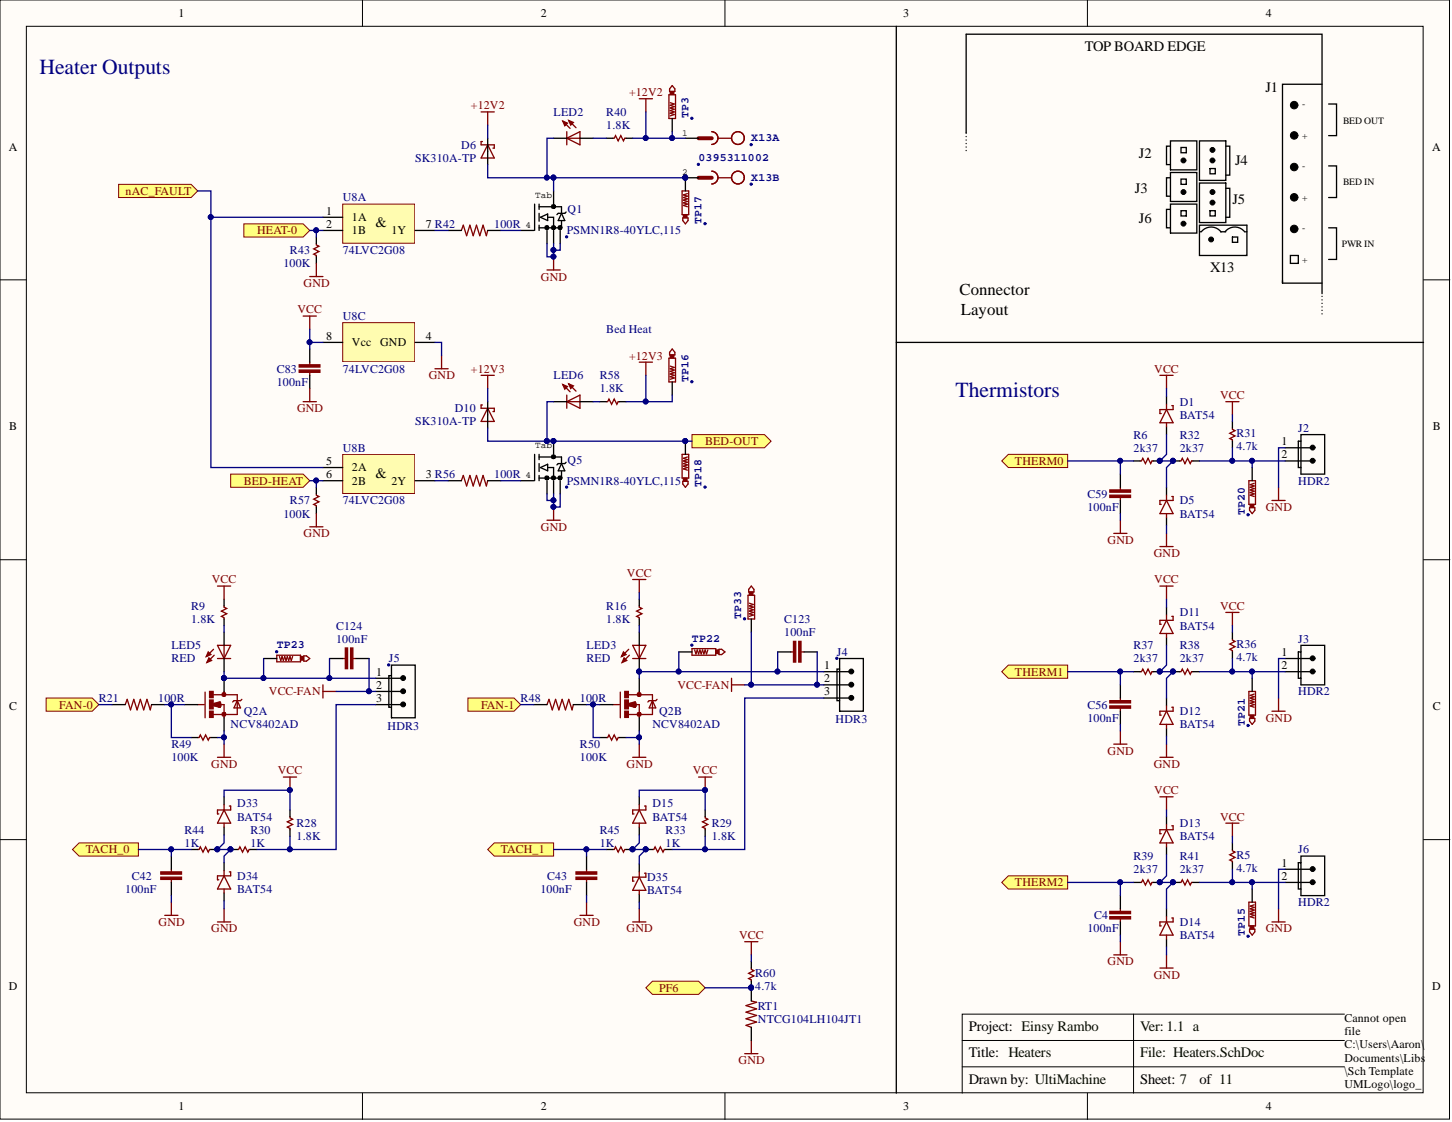
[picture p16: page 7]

Project: Einsy Rambo | Ver: 1.1 a

Heaters | Heaters.SchDoc

UltiMachine | 7 11

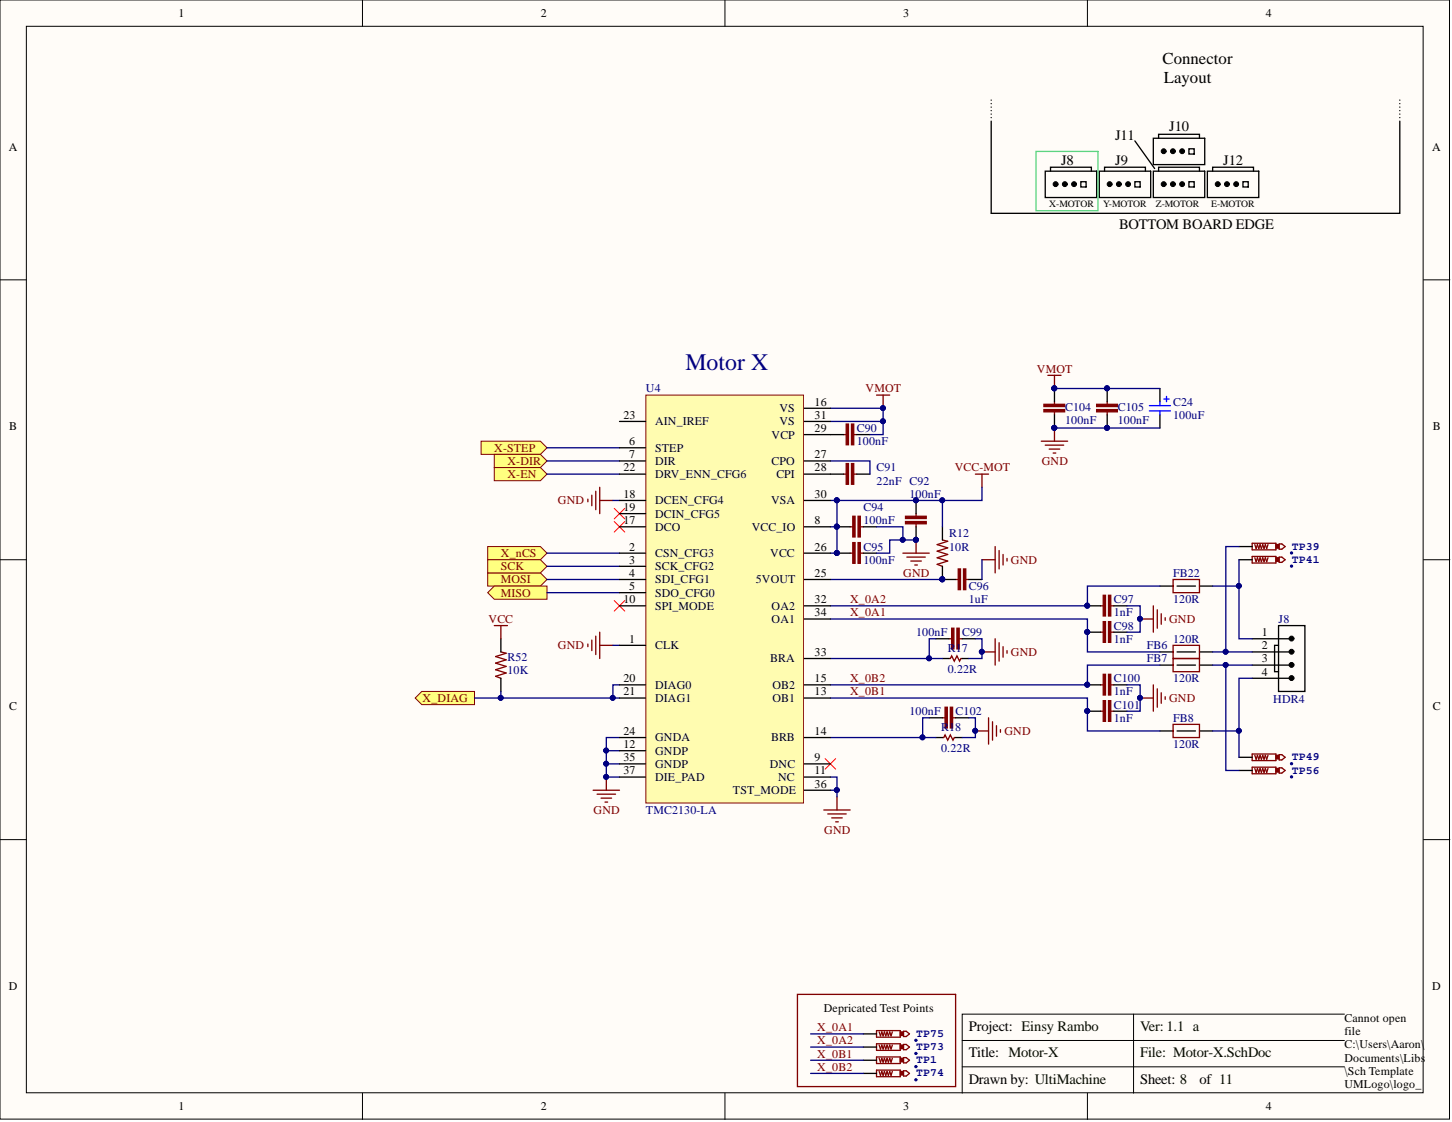
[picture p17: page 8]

CLK 1 | X_0A1

DIAG1 21 GNDA 24 | X_0B1

Project: Einsy Rambo | Ver: 1.1 a

Motor-X | Motor-X.SchDoc

UltiMachine | 8 11

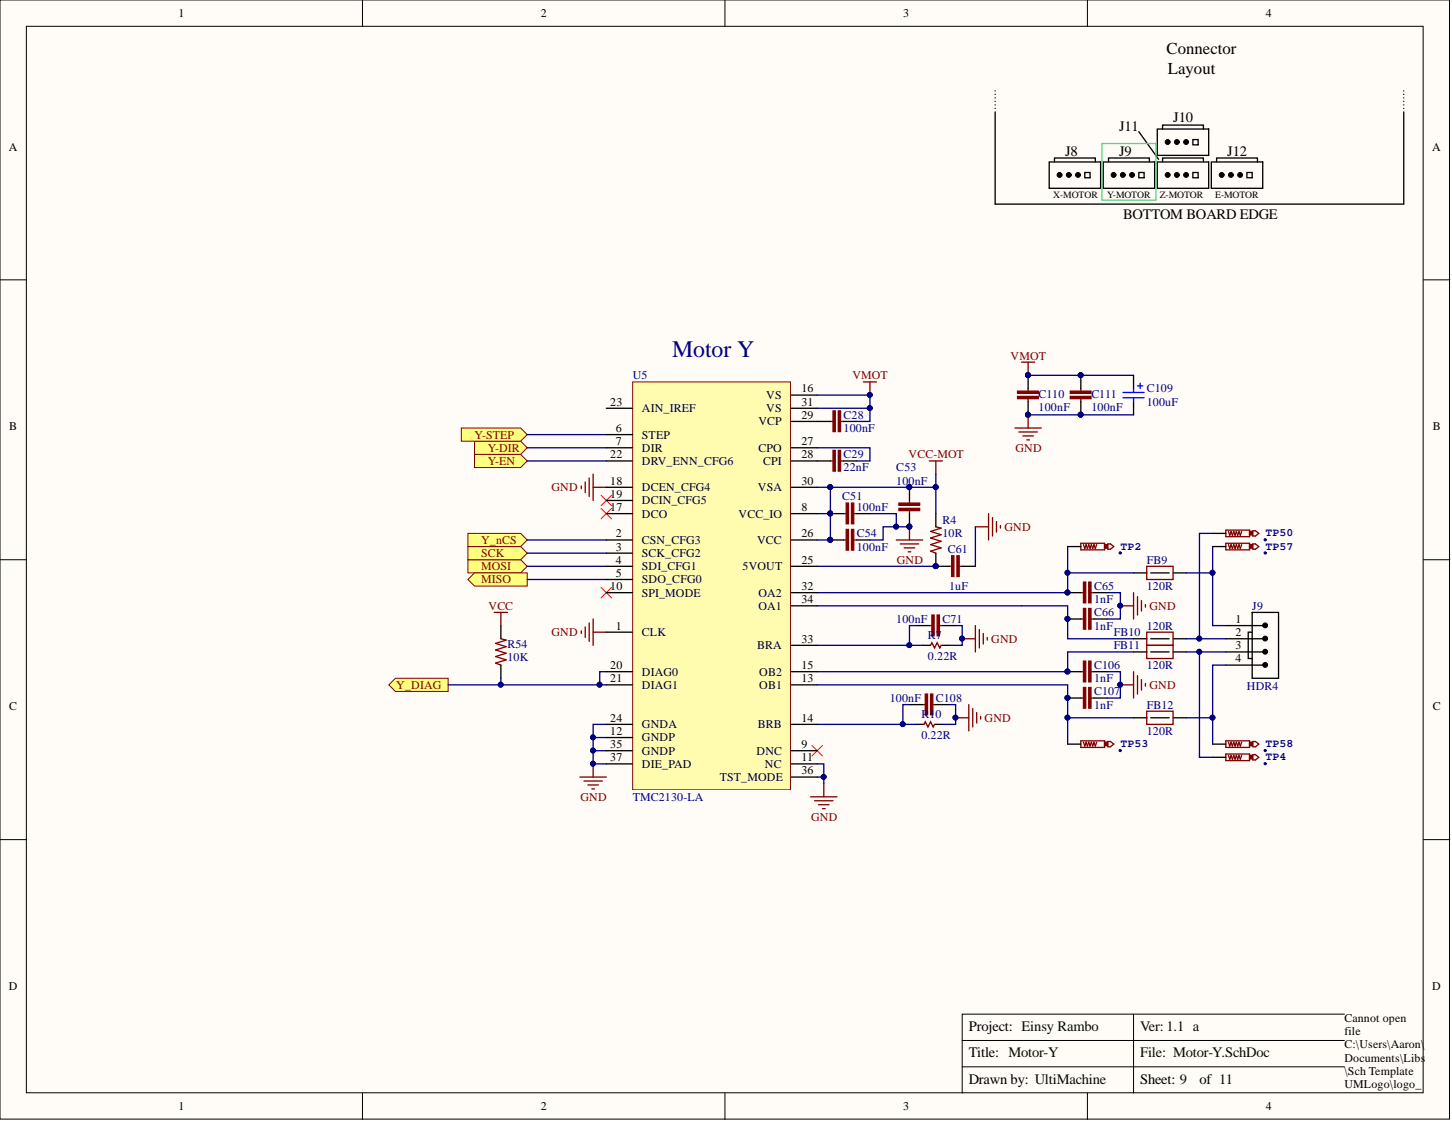
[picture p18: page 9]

Project: Einsy Rambo | Ver: 1.1 a

Motor-Y | Motor-Y.SchDoc

UltiMachine | 9 11

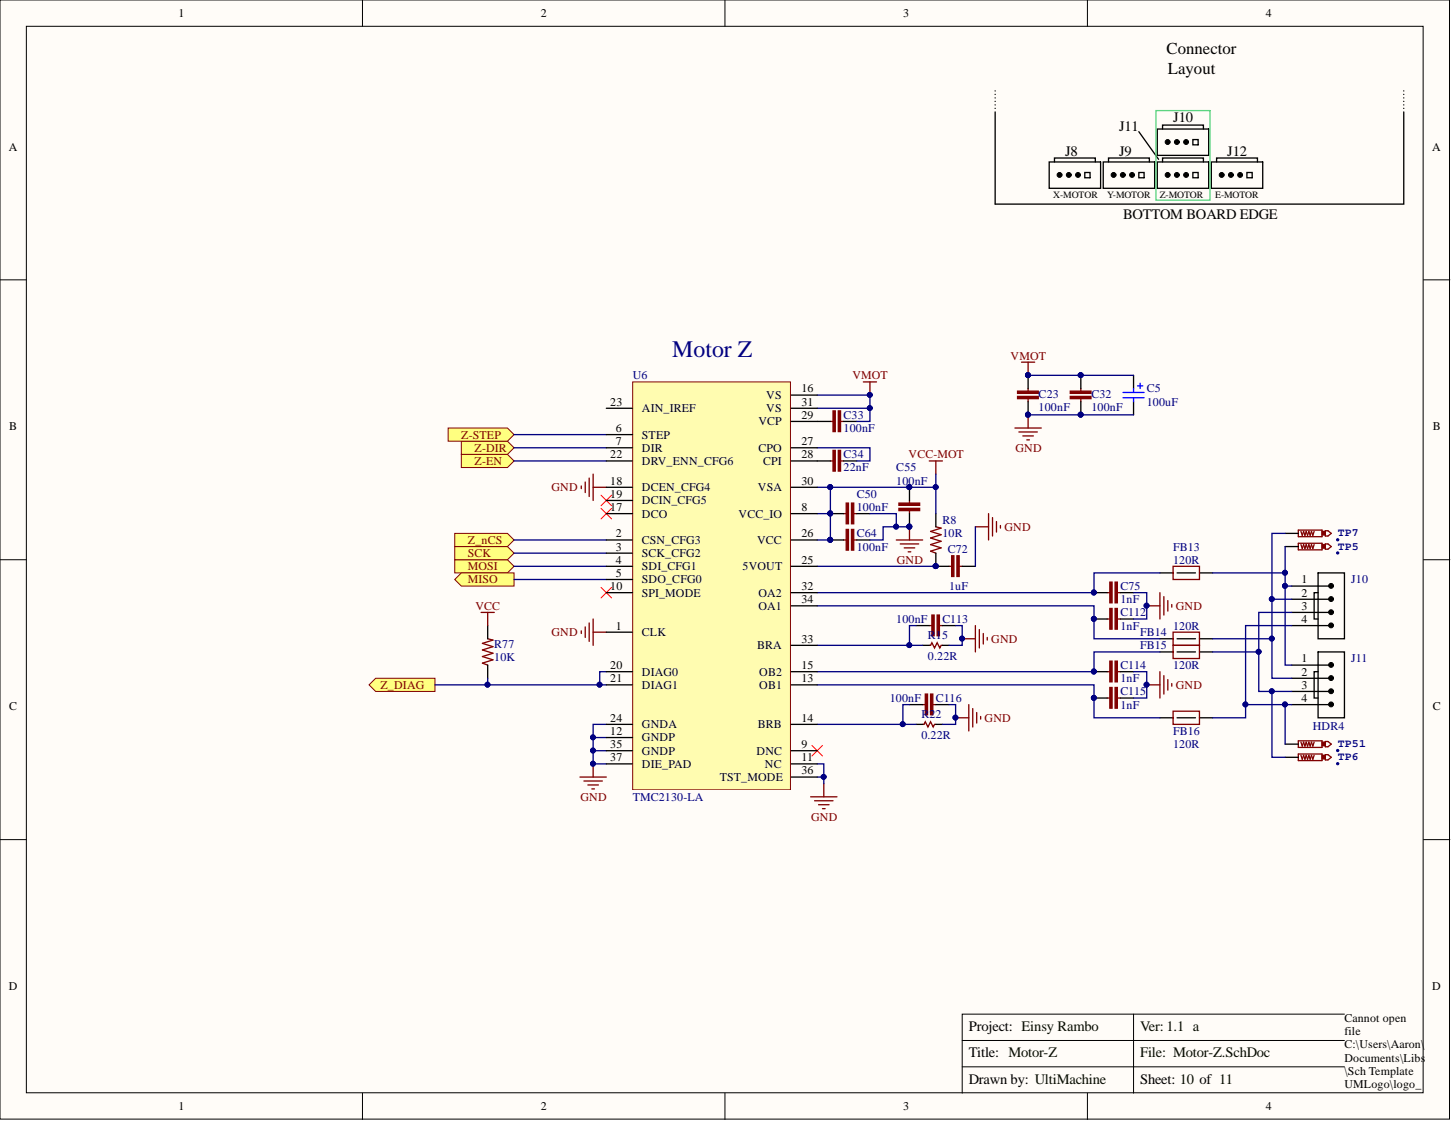
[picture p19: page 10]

Project: Einsy Rambo | Ver: 1.1 a

Motor-Z | Motor-Z.SchDoc

UltiMachine | 10 11

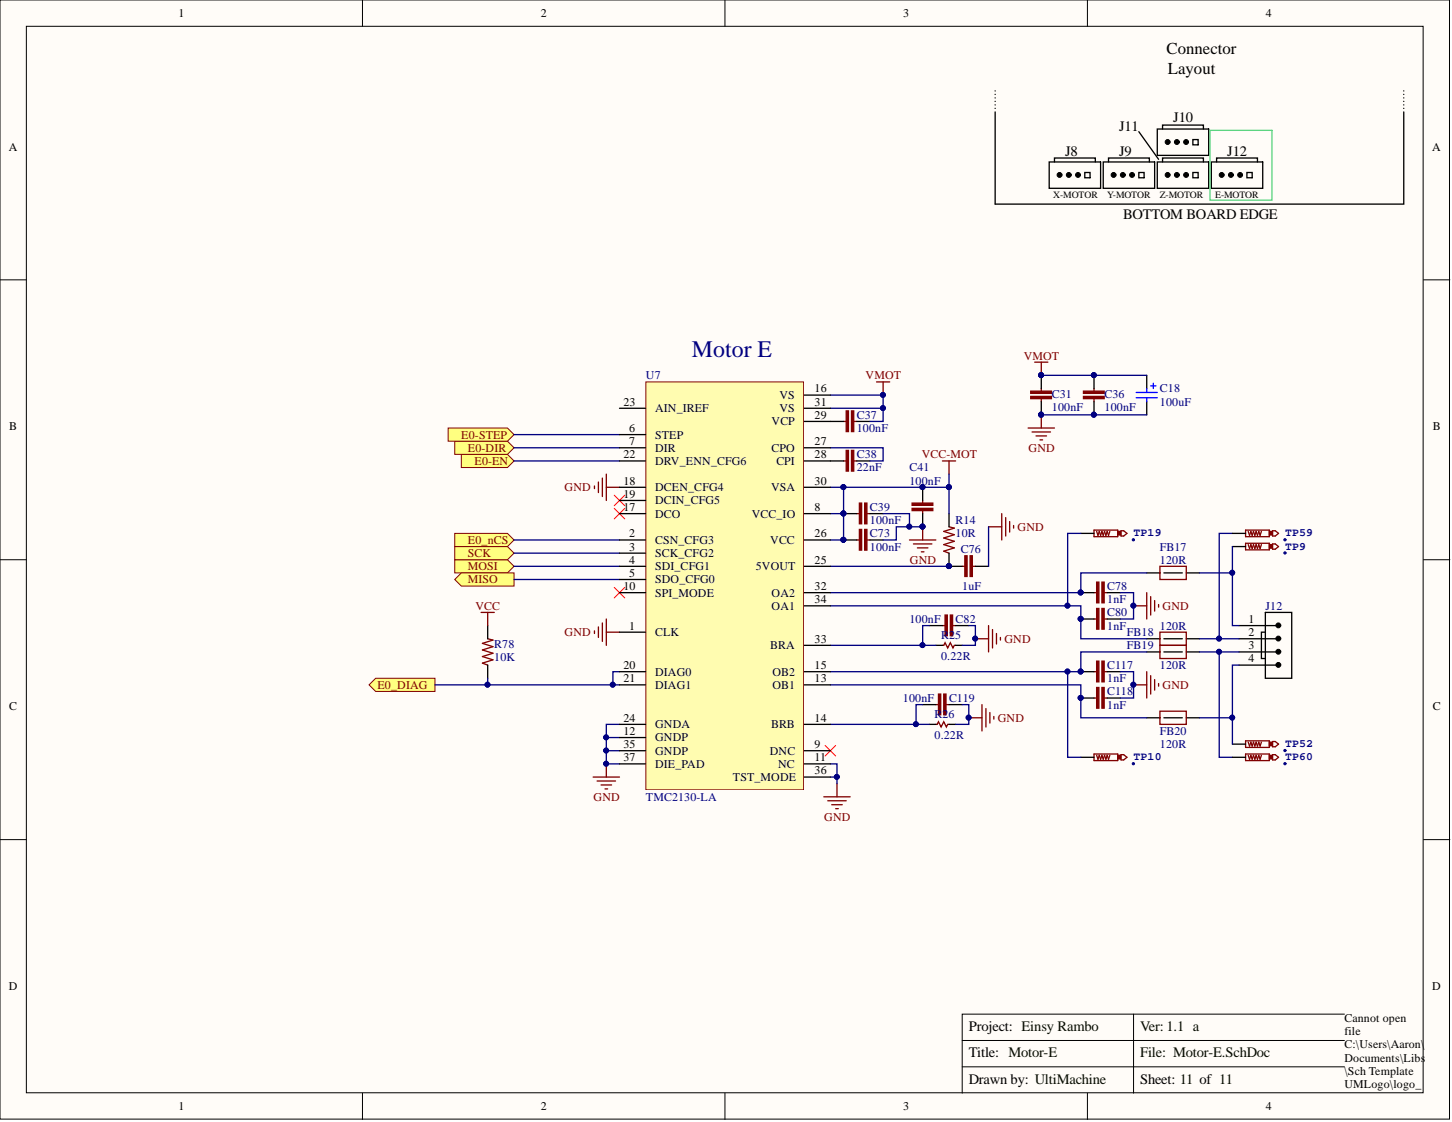
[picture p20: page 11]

Project: Einsy Rambo | Ver: 1.1 a

Motor-E | Motor-E.SchDoc

UltiMachine | 11 11

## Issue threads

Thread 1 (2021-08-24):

Octopus erste Auffälligkeiten

OXERY, 2021-08-24:
Hier die ersten Auffälligkeiten beim Test des Octopus Boards in Zusammenhang mit der Universal Config
- [ ] "neue" Mesh-Methode deaktivieren
- [ ] probe speed von 1.0 auf 5.0 stellen
- [ ] probe samples auf 5 erhöhen (wie früher?)
- [ ] (oder bei samples_result: average stattdessen auf median? Falls eine Messung falsch ist)
- [ ] Bei Filament-Unload wird der Display-Text hinterher nicht auf "leer" zurückgesetzt

OXERY, 2021-08-24:
- [ ] Nach PID-Tuning (egal ob Bed oder Extruder) kann man die Parameter mit save_config nicht speichern ("!! SAVE_CONFIG section 'extruder' option 'control' conflicts with included value")

OXERY, 2021-08-24:
Beim Aktivieren der pi adxl cfg kommt nach Neustart "Unknown spi_bus 'spi3'"

Prutsium, 2021-09-01:
All issues have been resolved in Universal Config Revised

Closed 2021-09-01.

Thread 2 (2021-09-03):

Einsy pins.cfg

sdooweloc, 2021-09-03:
In the pins.cfg for Boards/Einsy/pins.cfg there is a stray comma that causes compile errors as seen below between x_uart_pin and x_tx_pin's entries.

Also this is labeled as octopus_11_tmc2209 instead of something more einsy related like einsy_2130?

https://github.com/Prutsium/3D-Druckerplausch-Klipper/blob/8950a571f9cff511c0ee520111bf97c7c5b77ea3/Klipper_cfg/Prusa_Universal_Config_Revised/Boards/Einsy/pins.cfg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

Prutsium, 2021-09-03:
Both are fixed thanks for the heads-up.
Also i have disabled the plot_graph menu sections by default so it wont error out.
When you want to use it you need the patch from KIAUH for example to execute shell commands

sdooweloc, 2021-09-03:
Perfect thank you!

Closed 2021-09-03.

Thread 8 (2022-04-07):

unable to resolve when copying config

kaisarantonn, 2022-04-07:
pi@mainsailos:~ $ git clone https://github.com/Prutsium/3D-Druckerplausch-Klipper.git
Cloning into '3D-Druckerplausch-Klipper'...
fatal: unable to access 'https://github.com/Prutsium/3D-Druckerplausch-Klipper.git/': Could not resolve host: github.com

please help

Prutsium, 2022-04-07:
Yeah ... the repo has not been setup to be cloned into your
printer_config.
Better just grab the zip and take the right dir to your folder.

(still something we must arrange btw that it could be done :) )

------ Original Message ------
From: "kaisarantonn" ***@***.***>
To: "Prutsium/3D-Druckerplausch-Klipper"
***@***.***>
Cc: "Subscribed" ***@***.***>
Sent: 07/04/2022 21:36:22
Subject: [Prutsium/3D-Druckerplausch-Klipper] unable to resolve when
copying config (Issue #8)

>
***@***.***:~ $ git clone
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
***@***.***>
>

Closed 2022-04-08.

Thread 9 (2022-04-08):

Stuck after flashing

kaisarantonn, 2022-04-08:
When flashing atmega with your guide, the both of fans spins and this screen appear
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
But the star indicator is moving left and right.

But

After flashing atmega etc. using kiauh via USB. The star stopped and nothing happend. Screen is stuck and fans keep spinning

Help me please

acdarby, 2022-04-26:
I had this issues when re-flashing but I just turned the printer off and on (I guess not the best way) - then restarted the flash from the command line.
I don't use Kiauh for updates only the initial install. see the https://www.klipper3d.org/Installation.html guide and the "Building and flashing the micro-controller" for the Instructions that worked for me. Hope that helps a bit!

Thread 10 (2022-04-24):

Out of range error

acdarby, 2022-04-24:
I am getting an error
at the start of mesh levelling:

Starting normal Bed Mesh
Move out of range: -14.000 -4.000 5.000 [0.000]

I think this is a problem with the code but not sure how to change it - can you help as I am running your default macros with Superslicer code as you suggest in the print_start macro comments

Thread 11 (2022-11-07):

X/Y Homing Current Too Low

streaky, 2022-11-07:
On many printers including mine and some other conversations I've seen on discord the homing current set in https://github.com/Prutsium/3D-Druckerplausch-Klipper/blob/main/Klipper_cfg/Prusa_Universal_Config_Revised/Macros/homing.cfg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 (same for Y axis) seems to be too low, 130mA doesn't appear to be enough to counteract even small amounts of friction. I raised mine to 0.35 same as nominal current and it seems to resolve the issue - maybe it should be a multiplier that's configurable or some such, but 0.13 doesn't appear to be enough and it takes a lot of debugging to find the cause.

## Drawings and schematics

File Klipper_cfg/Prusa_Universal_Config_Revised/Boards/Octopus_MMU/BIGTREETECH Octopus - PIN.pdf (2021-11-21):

# ART FILM - TOP_TEXT

## MOTOR0

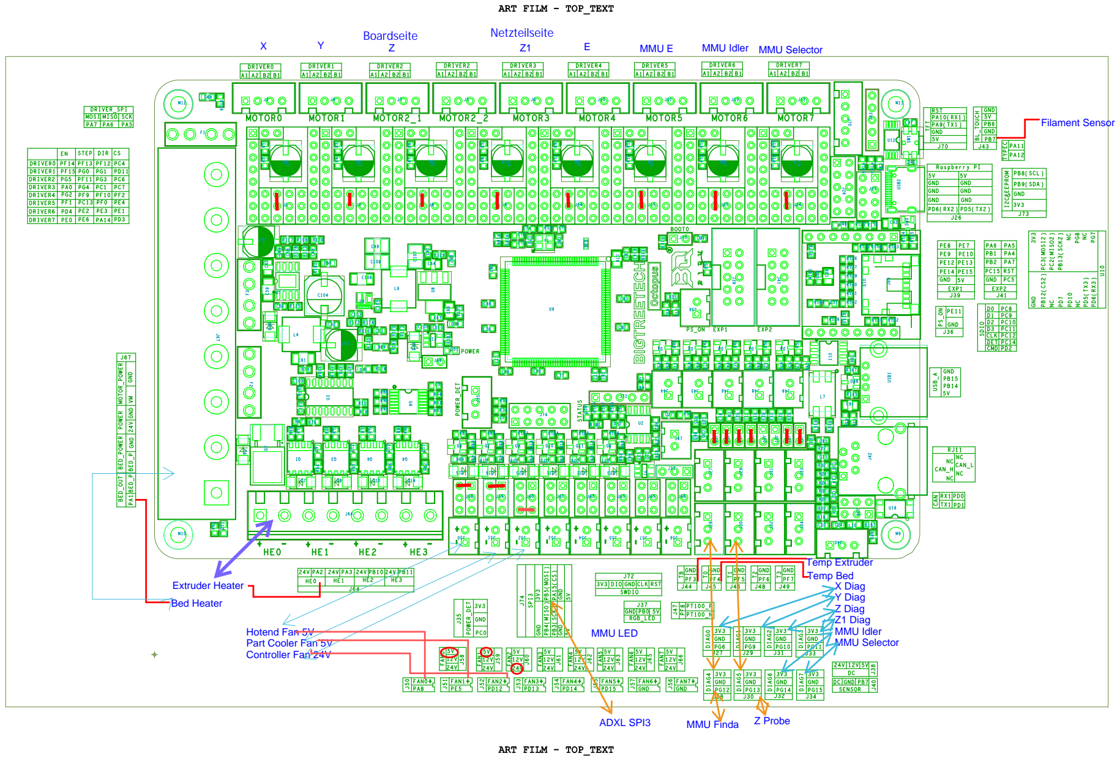
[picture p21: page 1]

MOSI | MISO | SCK

DRIVER1 | PF15 | PG0 | PG1 | PD11
DRIVER2 | PG5 | PF11 | PG3 | PC6
DRIVER3 | PA0 | PG4 | PC1 | PC7

DRIVER5 | PF1 | PC13 | PF0 | PE4

DRIVER6 | PD4 | PE2 | PE3 | PE1

DRIVER7 | PE0 | PE6 | PA14 | PD3

24V | PA2 | 24V | PA3 | 24V | PB10 | 24V | PB11
HE0 | | HE1 | | HE2 | | HE3

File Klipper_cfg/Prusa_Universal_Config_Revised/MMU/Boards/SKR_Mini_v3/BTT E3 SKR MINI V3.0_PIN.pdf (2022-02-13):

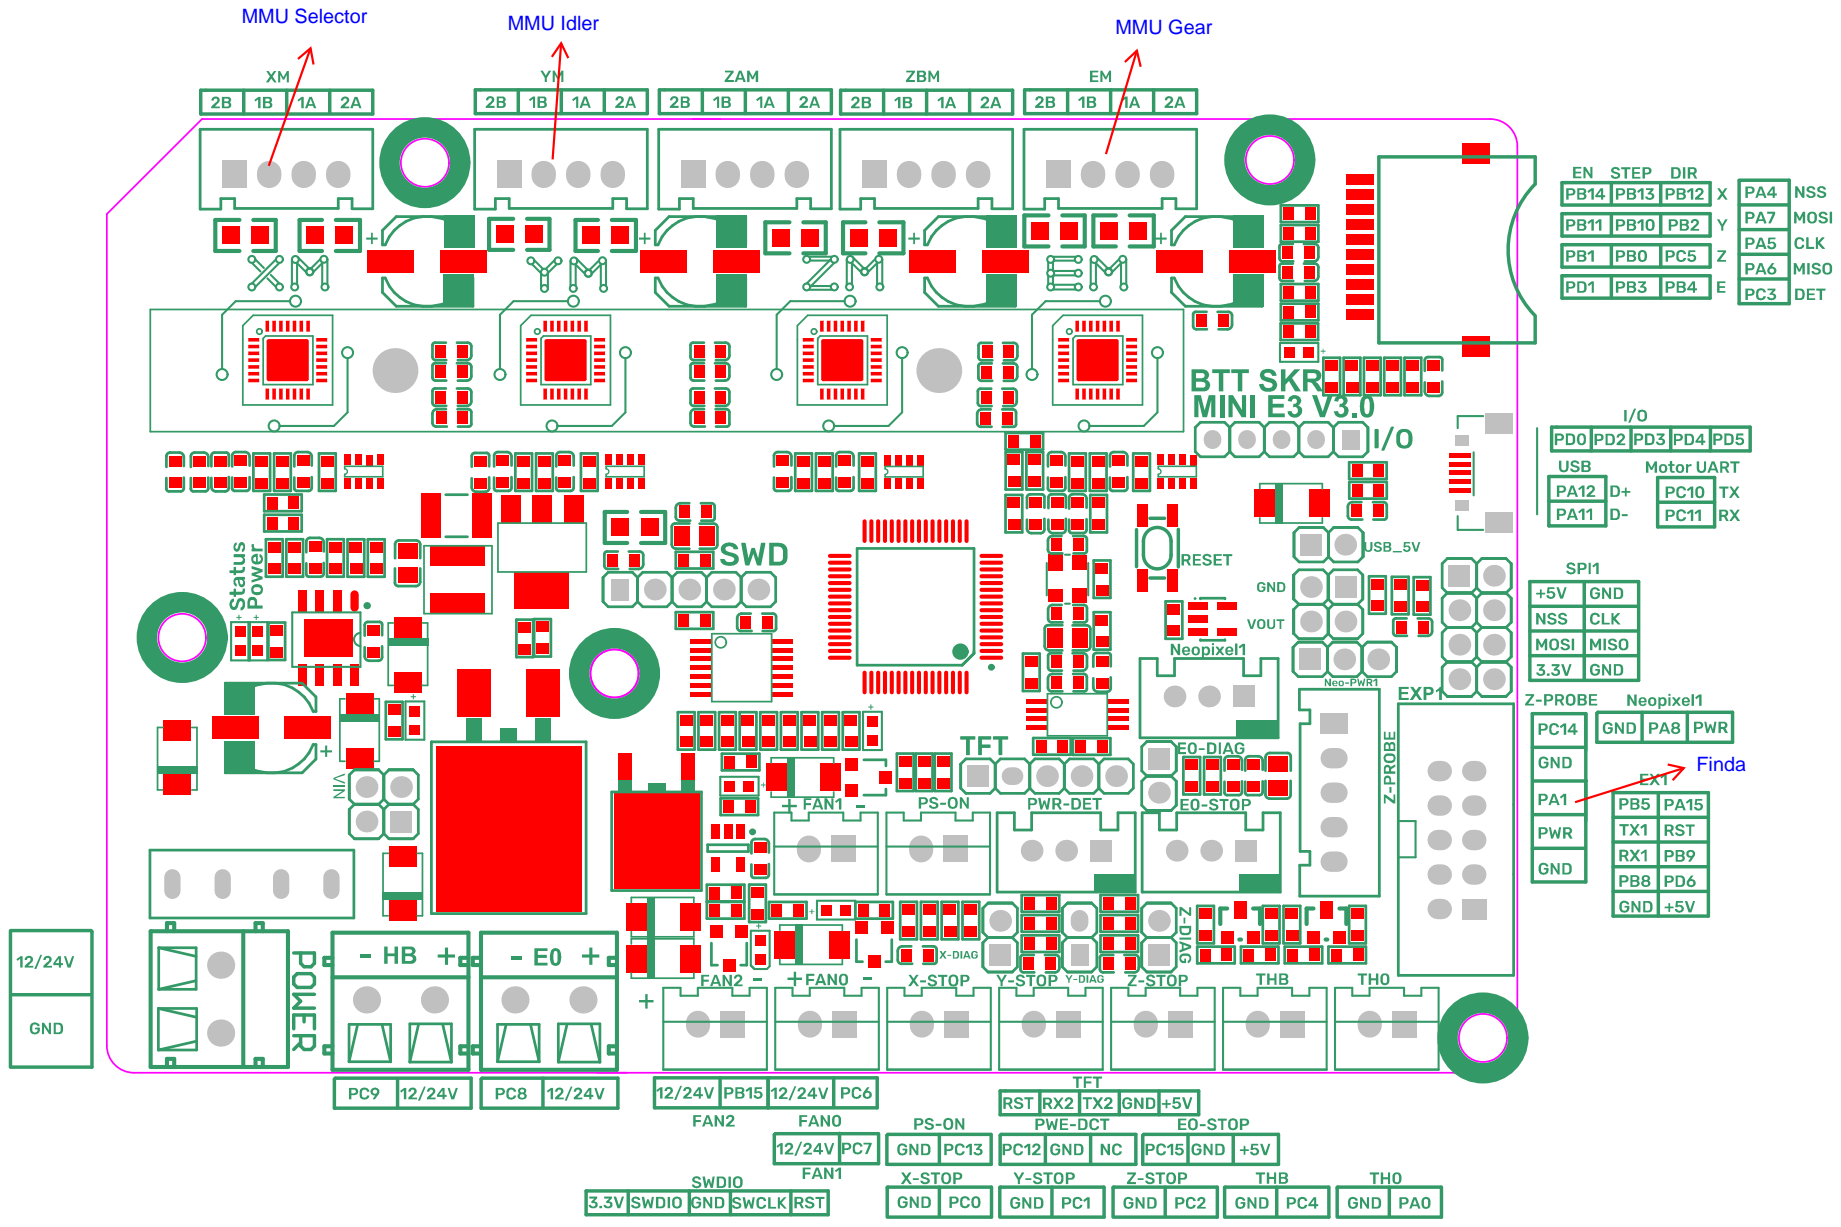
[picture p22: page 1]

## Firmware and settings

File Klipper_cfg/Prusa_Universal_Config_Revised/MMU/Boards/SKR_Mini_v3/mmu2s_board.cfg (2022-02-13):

# Configuration for DIY MMU2S based on SKR-MINI E3 V3
# This file contains common pin mappings for the BIGTREETECH SKR mini
# E3 v3.0. To use this config, the firmware should be compiled for the
# STM32G0B1 with a "8KiB bootloader" and USB communication.

# The "make flash" command does not work on the SKR mini E3. Instead,
# after running "make", copy the generated "out/klipper.bin" file to a
# file named "firmware.bin" on an SD card and then restart the SKR
# mini E3 with that SD card.

# See docs/Config_Reference.md for a description of parameters.
########################################
#
# Configuration for a SKR MINI E3 V3 board with TMC2209 UART
#
########################################
[mcu mmu]
# Add here the right MCU
serial: /dev/serial/by-id/usb-Klipper_stm32f103xe_37FFD3055358353225541643-if00
#restart_method: command

[respond]
default_type: command

#########################################										
# E0 : MMU2S 5mm rod with the 5 gears
[tmc2209 manual_stepper gear_stepper]
uart_pin: mmu:PC11
tx_pin: mmu:PC10
uart_address: 3
run_current: 0.800
hold_current: 0.200
interpolate: true
sense_resistor: 0.110
stealthchop_threshold: 999999
driver_SGTHRS: 75

[manual_stepper gear_stepper]
step_pin: mmu:PB3
dir_pin: !mmu:PB4
enable_pin: !mmu:PD1
microsteps: 16
# 140 : mk8 gear
#rotation_distance: 22.857
# 165 : fystec gear for mmu2s
rotation_distance: 19.394
velocity: 15
accel: 4000 # Same as Printer Acceleration
endstop_pin: mmu:PA1 #Finda

#########################################										
# Y : MMU2S idler with the 5 ball bearings
[tmc2209 manual_stepper idler_stepper]
uart_pin: mmu:PC11
tx_pin: mmu:PC10
diag_pin: ^mmu:PC1
uart_address: 2
run_current: 0.400 #800
hold_current: 0.200 #800
interpolate: true
sense_resistor: 0.110
stealthchop_threshold: 999999
driver_SGTHRS: 70                                  #0-255 sensorless homing sensitivity 0= less senstive 255= more sensitive


[manual_stepper idler_stepper]
step_pin: mmu:PB10
dir_pin: !mmu:PB2
enable_pin: !mmu:PB11
microsteps: 16
rotation_distance: 128
velocity: 100
accel: 80
endstop_pin: tmc2209_idler_stepper:virtual_endstop
homing_retract_dist: 0					  

#########################################										 
# X : MMU2S color selector
[tmc2209 manual_stepper selector_stepper]
uart_pin: mmu:PC11
tx_pin: mmu:PC10
diag_pin: ^mmu:PC0
uart_address: 0
run_current: 0.400 #1000
hold_current: 0.200 #400
interpolate: true
sense_resistor: 0.110
stealthchop_threshold: 999999
driver_SGTHRS: 70                                  #0-255 sensorless homing sensitivity 0= less senstive 255= more sensitive


[manual_stepper selector_stepper]
step_pin: mmu:PB13
dir_pin: !mmu:PB12
enable_pin: !mmu:PB14
# 80 step/mm
microsteps: 16
rotation_distance: 8
velocity: 35
accel: 100
endstop_pin: tmc2209_selector_stepper:virtual_endstop
#endstop_pin: !mmu:PC0 # switch endstop on the left Z-
homing_retract_dist: 0

	

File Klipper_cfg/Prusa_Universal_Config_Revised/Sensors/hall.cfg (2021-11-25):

[hall_filament_width_sensor]

#octopus
adc1: PF5
adc2: PF6
# adc1 and adc2 channels select own pins Analog input pins on 3d printer board
# Sensor power supply can be 3.3v or 5v

Cal_dia1: 1.50 # Reference diameter point 1 (mm)
Cal_dia2: 2.00 # Reference diameter point 2 (mm)

# The measurement principle provides for two-point calibration
# In calibration process you must use rods of known diameter
# I use drill rods as the base diameter.
# nominal filament diameter must be between Cal_dia1 and Cal_dia2
# Your size may differ from the indicated ones, for example 2.05

Raw_dia1:10630 # Raw sensor value for reference point 1
Raw_dia2:8300  # Raw sensor value for reference point 2

# Raw value of sensor in units
# can be readed by command QUERY_RAW_FILAMENT_WIDTH

default_nominal_filament_diameter: 1.75 # This parameter is in millimeters (mm)

max_difference: 0.15
# Maximum allowed filament diameter difference in millimeters (mm)
# If difference between nominal filament diameter and sensor output is more
# than +- max_difference, extrusion multiplier set back to %100

measurement_delay: 70
# The distance from sensor to the melting chamber/hot-end in millimeters (mm).
# The filament between the sensor and the hot-end will be treated as the default_nominal_filament_diameter.
# Host module works with FIFO logic. It keeps each sensor value and position in
# an array and POP them back in correct position.

enable:False
# Sensor enabled or disabled after power on. Disabled by default

# measurement_interval:10
# Sensor readings done with 10 mm intervals by default. If necessary you are free to change this setting

#logging: False
#  Out diameter to terminal and klipper.log
#  can be turn on|of by command

#Virtual filament_switch_sensor suppurt. Create sensor named hall_filament_width_sensor.
#
#min_diameter:1.0
#Minimal diameter for trigger virtual filament_switch_sensor.
#use_current_dia_while_delay: False
#   Use the current diameter instead of the nominal diamenter while the measurement delay has not run through.
#
#Values from filament_switch_sensor. See the "filament_switch_sensor" section for information on these parameters.
#
#pause_on_runout: True
#runout_gcode:
#insert_gcode:
#event_delay: 3.0
#pause_delay: 0.5

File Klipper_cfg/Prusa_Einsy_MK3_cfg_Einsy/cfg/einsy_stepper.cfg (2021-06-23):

#####################################################################
#   Ths file contains the XYZ stepper configs for the Einsy board
#####################################################################
#####################################################################
#   Einsy X/Y Stepper Settings
#####################################################################
[stepper_x]
step_pin: PC0
dir_pin: !PL0
enable_pin: !PA7
rotation_distance: 32           #16T Pulley, 2mm Belt Pitch
microsteps: 16
full_steps_per_rotation: 200    #200 for 1.8 degree, 400 for 0.9 degree
endstop_pin: tmc2130_stepper_x:virtual_endstop
position_endstop: 0
position_max: 250
homing_speed: 50
homing_retract_dist: 0

[tmc2130 stepper_x]
cs_pin: PG0
interpolate: True
run_current: .281738
hold_current: .281738
sense_resistor: 0.220
diag1_pin: !PK2
driver_IHOLDDELAY: 8
driver_TPOWERDOWN: 0
driver_TBL: 2
driver_TOFF: 3
driver_HEND: 1
driver_HSTRT: 5
driver_PWM_FREQ: 2
driver_PWM_GRAD: 2
driver_PWM_AMPL: 230
driver_PWM_AUTOSCALE: True
driver_SGT: 2

[stepper_y]
step_pin: PC1
dir_pin: PL1
enable_pin: !PA6
rotation_distance: 32           #16T Pulley, 2mm Belt Pitch
microsteps: 16
full_steps_per_rotation: 200    #200 for 1.8 degree, 400 for 0.9 degree
endstop_pin: tmc2130_stepper_y:virtual_endstop
position_endstop: -4
position_max: 210
position_min: -4
homing_speed: 50
homing_retract_dist: 0

[tmc2130 stepper_y]
cs_pin: PG2
interpolate: True
run_current: .3480291
hold_current: .3480291
sense_resistor: 0.220
diag1_pin: !PK7
driver_IHOLDDELAY: 8
driver_TPOWERDOWN: 0
driver_TBL: 2
driver_TOFF: 3
driver_HEND: 1
driver_HSTRT: 5
driver_PWM_FREQ: 2
driver_PWM_GRAD: 2
driver_PWM_AMPL: 235
driver_PWM_AUTOSCALE: True
driver_SGT: 2

#####################################################################
#   Einsy Z Stepper Settings
#####################################################################
[stepper_z]
step_pin: PC2
dir_pin: !PL2
enable_pin: !PA5
rotation_distance: 8            # Rotation Distance for TR8x8 = 8, TR8x4 = 4, TR8x2 = 2
microsteps: 16
full_steps_per_rotation: 200    #200 for 1.8 degree, 400 for 0.9 degree
endstop_pin: probe:z_virtual_endstop
position_max: 210
position_min: -2
homing_speed: 13.333

[tmc2130 stepper_z]
cs_pin: PK5
interpolate: True
run_current: .53033
hold_current: .53033
sense_resistor: 0.220
diag1_pin: !PK6
driver_IHOLDDELAY: 8
driver_TPOWERDOWN: 0
driver_TBL: 2
driver_TOFF: 3
driver_HEND: 1
driver_HSTRT: 5
driver_PWM_FREQ: 2
driver_PWM_GRAD: 4
driver_PWM_AMPL: 200
driver_PWM_AUTOSCALE: True
driver_SGT: 4

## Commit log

2021-04-26 Innitial setup
    printer.cfg based on includes to make sharing easier.
    [macros.cfg, orbiter_extruder.cfg, pi_mcu.cfg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]
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2021-04-28 Update to stock extruder default + Marlin vs Klipper image
    [printer.cfg]
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2021-05-03 Remove & Updates
    Removed Sheetmanager and replaced by Flexplate and added some minor tweaks
    [deactivated-sheetmanager.cfg, flexplate.cfg, macros.cfg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]
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2021-05-14 MMU with Klipper
    Config files for a Prusa with Stock Extruder and MMU with a SKR Mini E3 V2 controller board.
    [deactivated-sheetmanager.cfg, flexplate.cfg, macros.cfg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]
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2021-05-17 Reworked MMU approach
    Thanks to @bad1dea for rework
    [flexplate.cfg, macros.cfg, mmu2s-board.cfg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]
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2021-05-18 Reworked approach
    Better handling of loading / unloading
    [mmu2s-board.cfg, mmu2s-config.cfg, mmu2s.cfg]
2021-05-19 Fully reworked scripts
    Thanks to Bad1dea scripts have been optimzed
    [macros.cfg, mmu2s-board.cfg, mmu2s-config.cfg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]
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2021-05-19 Bugfix due renaming Pinda to Finda
    [mmu2s-config.cfg, mmu2s.cfg]
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2021-05-20 Fix minor bug in end script
    [mmu2s.cfg]
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2021-05-20 mmu: added variable to use idler assist or not during filament load
    [mmu2s-config.cfg, mmu2s.cfg, variables.cfg]
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2021-05-21 Some tweaks in loading script and updated colors Neopixel
    [mmu2s-config.cfg, mmu2s.cfg, neopixel.cfg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]
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2021-05-22 Added files for SKR Mini E3 V2 board and Status light
    [MMU Status LED - Background letters White.stl, MMU Status LED - Case Black.stl, MMU Status LED - Letters Black.STL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]
2021-05-22 Loading tweaks and End code fix
    [mmu2s-config.cfg, mmu2s.cfg]
2021-05-22 Mesh position to screws and optimized Screw Assist
    [printer.cfg, screw_adjust.cfg]
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2021-06-10 Removed not working MMU2 cfg
    [MMU Status LED - Background letters White.stl, MMU Status LED - Case Black.stl, MMU Status LED - Letters Black.STL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]
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2021-06-10 Fix Zprobe retract and better MMU loading with Sync stepper
    [mmu2s-config.cfg, mmu2s.cfg, printer.cfg]
2021-06-10 WS281x LED Strip Macro (Using Python Script + Shell Commands)
    [macro.cfg]
2021-06-23 Added configuration for Duet 3 Mini 5+ on the MK3(S) with Klipper
    [flexplate.cfg, macros.cfg, neopixel.cfg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]
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2021-06-24 Lowered X/Y stepper currents and Max Velocity reduced
    [printer.cfg]
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2021-07-02 Fix Click Pin so display goes to start screen
    [mini12864.cfg]
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2021-07-02 Pre work for the Ratrig with Spider board
    [FyseTc_Spider_printer.cfg, Spider pinout.xlsx]
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2021-07-20 Added fix for long waiting in Start gcode info
    [printer.cfg]
2021-07-20 Fix for long waiting in Start Gcode info
    [macros.cfg]
2021-07-20 Added ADXL direct on Octopus and Octopus Temp boardsensor
    [printer.cfg]
2021-07-26 PA Speeds based and Printing Feature added
    Based on the Printing speed the PA value will be calculated as PA changes on different speeds.
    Also the accelerations will adapt based on the printing feature requested (solid, infill, etc etc)
    [pa_speed_adaption.cfg, printer.cfg, printing_feature.cfg]
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2021-07-26 Due minor issues PA Speed adaption disabled for now
    [printer.cfg]
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2021-07-26 PA Automatic adaption set active
    Due minor typo the PA automatic adaption was de-activated. Fixed and active again.
    Currently it grabs only the G0 ones in near future G1 & G2 will be added.
    [printer.cfg]
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2021-08-01 Removed PA adaption again as it does not work well
    [macros.cfg, pa_speed_adaption.cfg, printer.cfg]
2021-08-02 Removed PA Adaption & Tasmota Switch to be universal
    [printer.cfg]
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2021-08-04 Removed PA adation and added purge line macro
    [macros.cfg, pa_speed_adaption.cfg, printer.cfg]
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2021-08-15 Moved filament load / unload to its own config
    [filament_load.cfg, macros.cfg, printer.cfg]
2021-08-15 Changed behaiviour of M84 where only XY steppers are off
    To prevent sagging of the Z stepper these are kept on
    [macros.cfg, mmu2s.cfg]
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2021-08-15 Fix minor error double purge macro
    [macros.cfg]
2021-08-16 Preperation for Universal Prusa config(s)
    Doesnt work yet(!)
    [mmu2s-board.cfg, mmu2s-config.cfg, mmu2s.cfg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]
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2021-08-17 Cleaning up a bit
    Also added pin maps to Universal configs
    [MMU Status LED - Background letters White.stl, MMU Status LED - Case Black.stl, MMU Status LED - Letters Black.STL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]
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2021-08-18 All configs added new mesh & homing routines
    [Stock_Prusa_Duet3Mini5-printer.cfg, Stock_Prusa_Duet3Mini5_with_MMU-printer.cfg, Stock_Prusa_Einsy-printer.cfg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]
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2021-08-18 Bug fixes some directory errors
    [Stock_Prusa_Duet3Mini5-printer.cfg, Stock_Prusa_Duet3Mini5_with_MMU-printer.cfg, Stock_Prusa_Einsy-printer.cfg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]
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2021-08-22 Updated flexplate manager
    And added section for your own plates
    [Stock_Prusa_Duet3Mini5-printer.cfg, Stock_Prusa_Duet3Mini5_with_MMU-printer.cfg, Stock_Prusa_Einsy-printer.cfg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]
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2021-08-22 Fixed issue with TMC2209 vs TMC2130
    A variable must now be set when using TMC2209 to use correct homing routine
    [Stock_Prusa_Duet3Mini5-printer.cfg, Stock_Prusa_Duet3Mini5_with_MMU-printer.cfg, Stock_Prusa_Einsy_with_MMU-printer.cfg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]
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2021-08-22 Reverted Flexplate back to older version
    Some issues i must check with the author of this module
    [flexplate.cfg]
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2021-08-22 As new mesh generation is kinda slow the old method as backup
    [mesh_old.cfg]
2021-08-22 Minor fix
    [print_time.cfg]
2021-08-22 Pushed fix Flexplate again
    Grrrrr stupid Git :)
    [flexplate.cfg]
2021-08-22 Reverted back to old mesh method
    The new method gives me strange results
    [Stock_Prusa_Duet3Mini5-printer.cfg, Stock_Prusa_Duet3Mini5_with_MMU-printer.cfg, Stock_Prusa_Einsy-printer.cfg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]
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2021-08-23 Small mistake in naming
    [tasmotaswitch.cfg]
2021-08-23 Added default Z offset
    See readme for info
    [Stock_Prusa_Duet3Mini5-printer.cfg, Stock_Prusa_Duet3Mini5_with_MMU-printer.cfg, Stock_Prusa_Einsy-printer.cfg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]
2021-08-23 Quick fix for homing after starting from a previous print
    [mmu_start_print.cfg, start_print.cfg]
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2021-08-26 Revamped Universal Config
    Octopus & Octopus MMU only for now
    [MMU Status LED - Background letters White.stl, MMU Status LED - Case Black.stl, MMU Status LED - Letters Black.STL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]
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2021-08-27 Fixed some issue with steppers
    [stepper.cfg, tmc2209.cfg]
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2021-08-29 Brought 1 pin back to config due mapping issue
    [orbiter.cfg, printer_einsy.cfg, printer_octopus_mmu.cfg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]
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2021-08-29 Cleaned up so that Universal Revised will be default
    [Klipper settings JG.3mf, MMU Status LED - Background letters White.stl, MMU Status LED - Case Black.stl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]
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2021-08-29 Fix knob rotation direction
    [printer_duet3mini.cfg, printer_octopus_mmu.cfg]
2021-08-30 Made homing automatic current reduction
    Makes less noise when homing :)
    [mmu2s.cfg]
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2021-09-01 fixed typo in resonance test config
    [resonance_test.cfg]
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2021-09-01 Minor fixes PID
    [display_menu.cfg]
2021-09-01 Fix for Einsy no z_tilt
    [start_print.cfg]
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2021-09-03 Fixed config error
    There was a stray comma left over and also the naming has been fixed
    [pins.cfg]
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2021-09-03 Resonance test menu default off
    As Resonance test menu item requires the patch with Custom Shell commands in Klipper i have disabled this by default.
    [printer_example_Duet.cfg, printer_example_Einsy.cfg, printer_example_Octopus.cfg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]
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2021-09-05 Revised and improved End print
    Now calculates the Z lift at end
    [end_print.cfg, mmu_end_print.cfg]
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2021-09-06 Minrot fix End print macros
    [end_print.cfg, mmu_end_print.cfg]
2021-09-06 adxl selection into printer.cfg
    rename resonances_example to resonances.cfg and edit to your own resonance settings,
    [printer_example_Octopus_MMU.cfg, resonances_example.cfg]
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2021-09-06 Resonance tuning to own config
    rename resonances_example.cfg to resonances.cfg and add there the results of your resonance testing and enable it the printer.cfg
    [printer_example_Duet.cfg, printer_example_Einsy.cfg, printer_example_Octopus.cfg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]
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2021-09-06 Copied wrong file
    [resonance.cfg]
2021-09-06 Option always_mesh added
    in the printer.cfg you now can select if it always should generate a mesh by setting the option to 1.
    [mmu_start_print.cfg, printer_example_Duet.cfg, printer_example_Einsy.cfg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]
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2021-09-07 Fixed a few M118 error messages
    [mmu2s.cfg]
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2021-09-27 First implementation of the SKR 1.4 board
    For now quick hack but a working config at least
    [printer_example_SKR1.4.cfg, printer_skr1.4.cfg]
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2021-10-04 Bugfix first filament in start print mmu, added mmu led config
    [mmu2s_config.cfg, mmu2s_start.cfg, neopixel.cfg]
2021-10-07 Fixed wled control (hopefully)
    [wled.cfg]
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2021-10-20 Replaced all Default Parameters
    [macros.cfg, mmu2s_start.cfg, mmu2s_tool.cfg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]
2021-10-21 Took al MMU Display menu's to the MMU part as they could create issues
    [main.cfg, mmu2s.cfg, mmu2s_menu.cfg]
2021-10-21 Fixed minor error
    [main.cfg]
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2021-11-12 Revert "Updated currents for better homing"
    This reverts commit 6cbabfb3c24d28a6c52488b3780226402ed8342c.
    [homing.cfg]
2021-11-21 Fix Fan pins in drawing
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2022-01-03 Do not let nozzle cool down too much
    If nozzle temp is above 170°C it will be cooled down and heated up again to 170°C. This patch will cool down the nozzle to 170°C
    [start_print.cfg]
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2022-01-05 Removed Hold Current from Configs as recommended by Kevin
    as mentioned in https://github.com/Klipper3d/klipper/pull/4977
    "Don't use hold_current."
    [homing.cfg, mmu2s_board.cfg, mmu2s_home.cfg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]
2022-01-06 Fixed type _INIT_PLATE_ARRAY to INIT_PLATE_ARRAY
    [flexplate.cfg]
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2022-01-14 Bugfix flexplate, start_print order changed, added more magnets and dynamic leveling
    [flexplate.cfg, macros.cfg, mesh_magnets.cfg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]
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2022-02-17 Update tram_z.cfg
    Your tram_z macro references the x motor settings. I assume this is a typo?
    [tram_z.cfg]
